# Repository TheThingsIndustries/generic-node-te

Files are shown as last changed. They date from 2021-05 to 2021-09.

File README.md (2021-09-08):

# Generic Node Tracker Edition (GNTE)

## About

The Generic Node Tracker Edition provides a reference HW design that features [Semtech LR1110](https://www.semtech.com/products/wireless-rf/lora-edge/lr1110) modem and an STM32L073 host MCU.

This repository contains all the necessary hardware and software files for the GNTE node.

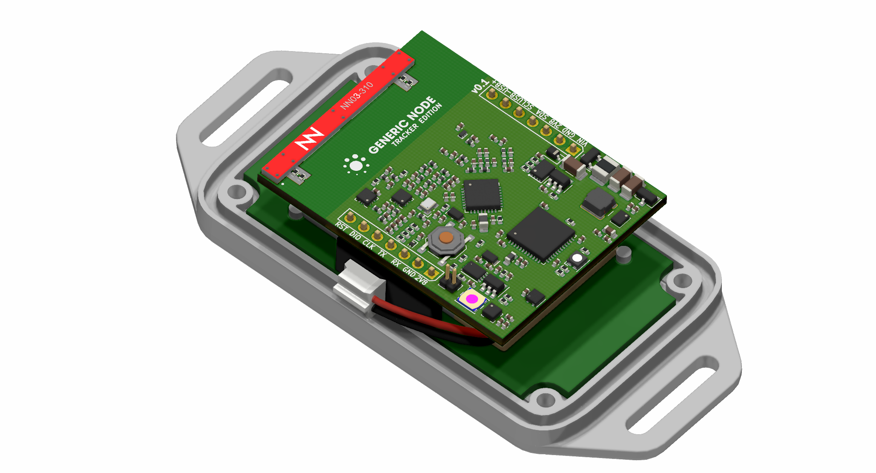
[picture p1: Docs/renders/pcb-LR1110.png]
Generic Node Tracker Edition PCB


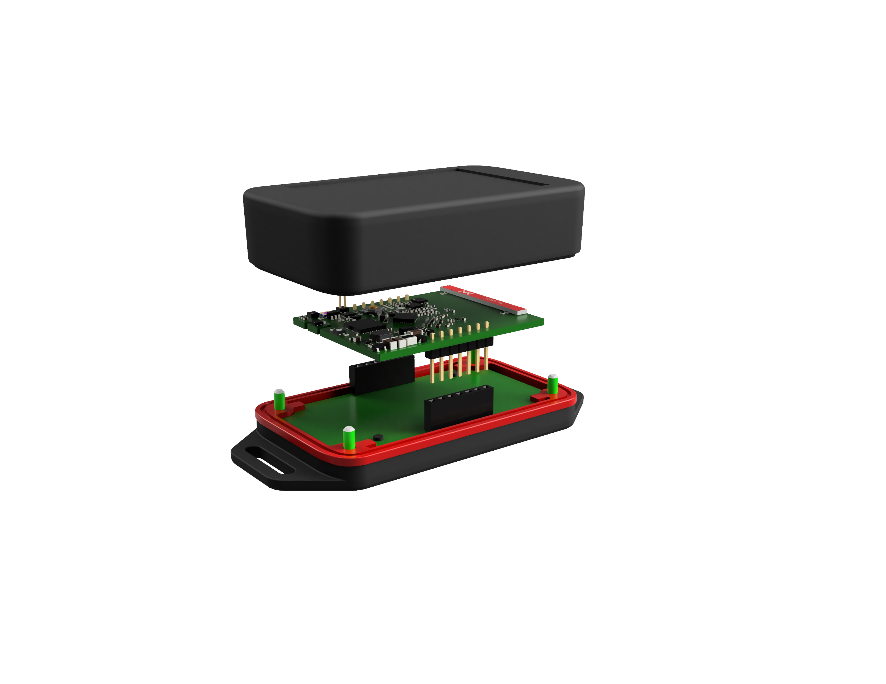
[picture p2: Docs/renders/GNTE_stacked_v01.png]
Generic Node Tracker Edition Stacked


## Documentation

The [Generic Node documentation website](https://www.genericnode.com/docs/) provides information about the node hardware and software features.

## Acknowledgment

The [Software](./Software) featured in this repository is a fork of Semtech [lr1110_modem_application_example](https://github.com/Lora-net/lr1110_modem_application_example) with minor changes that reflect the HW design.

## Legal

[Generic Node license terms and conditions](./LICENSE.md) apply.

[Contact The Things Industries](https://thethingsindustries.com/contact/) for licensing.

Copyright © 2021 The Things Industries B.V.

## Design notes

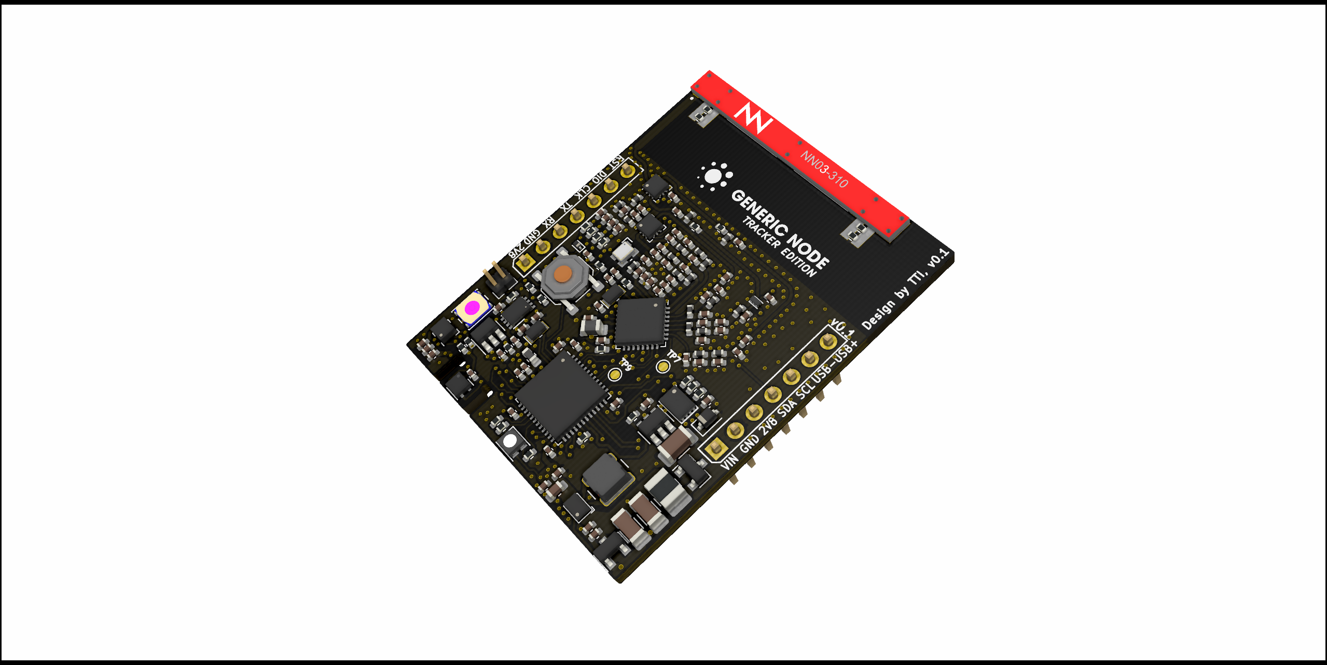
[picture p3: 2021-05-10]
Docs/renders/pcb-LR1110-02.png

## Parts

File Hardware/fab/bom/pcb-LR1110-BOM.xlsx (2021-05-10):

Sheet: pcb-LR1110
Source: | C:\Users\orkha\OneDrive\TTI_Files\Generic_Node_TE\Hardware\pcb\pcb-LR1110.sch
Date: | 2/17/2021 2:02:27 PM
Tool: | Eeschema (5.1.8)-1
Generator: | C:\Program Files\KiCad\bin\scripting\plugins/bom_csv_grouped_by_value.py
Component Count: | 150
Individual Components:
Collated Components:
Item | Qty | Reference(s) | Value | MPN | ALT_MPN | LibPart | Footprint
1 | 1 | AE1 | NN03-310 | NN03-310 |  | lr1110-lib:NN03-310 | lr1110-lib:NN03-310_S
2 | 7 | C1, C8, C11, C12, C43, C69, C70 | 1uF | CL05A105KQ5NNNC |  | Device:C | Capacitor_SMD:C_0402_1005Metric
3 | 14 | C2, C7, C10, C32, C33, C36, C37, C38, C40, C42, C67, C68, C71, C72 | 100nF | CC0402KRX7R7BB104 |  | Device:C | Capacitor_SMD:C_0402_1005Metric
4 | 3 | C3, C4, C5 | 100uF | JMK316ABJ107ML-T |  | Device:C | Capacitor_SMD:C_1206_3216Metric
5 | 1 | C6 | 470pF | CL05C471JO5NNNC |  | Device:C_Small | Capacitor_SMD:C_0402_1005Metric
6 | 1 | C9 | 22uF | CC0603MRX5R5BB226 | JMK107BBJ226MA | Device:C | Capacitor_SMD:C_0603_1608Metric
7 | 2 | C13, C34 | 100nF | CC0402KRX7R7BB104 |  | Device:C_Small | Capacitor_SMD:C_0402_1005Metric
8 | 2 | C14, C48 | 1.2pF | GRM1555C1H1R2BA01D |  | Device:C_Small | Capacitor_SMD:C_0402_1005Metric
9 | 7 | C15, C17, C47, C57, C58, C65, C66 | 1nF | GRM155R71C102KA01D |  | Device:C_Small | Capacitor_SMD:C_0402_1005Metric
10 | 5 | C16, C27, C28, C41, C46 | 47pF | GRM1555C1H470JA01D |  | Device:C_Small | Capacitor_SMD:C_0402_1005Metric
11 | 2 | C18, C30 | 6.8pF | GRM1555C1H6R8CA01D |  | Device:C_Small | Capacitor_SMD:C_0402_1005Metric
12 | 1 | C20 | 10pF | C0402C100K5RAC7867 |  | Device:C_Small | Capacitor_SMD:C_0402_1005Metric
13 | 1 | C21 | 1.8pF | GRM1555C1H1R8BA01D |  | Device:C_Small | Capacitor_SMD:C_0402_1005Metric
14 | 4 | C22, C23, C73, C74 | 5.6pF | CC0402BRNPO9BN5R6 |  | Device:C_Small | Capacitor_SMD:C_0402_1005Metric
15 | 1 | C24 | 2pF | GJM1555C1H2R0WB01 |  | Device:C_Small | Capacitor_SMD:C_0402_1005Metric
16 | 2 | C25, C52 | 1.1pF | GJM1555C1H1R1WB01 |  | Device:C_Small | Capacitor_SMD:C_0402_1005Metric
17 | 1 | C26 | 2.2nF | GRM155R71H222KA01D |  | Device:C_Small | Capacitor_SMD:C_0402_1005Metric
18 | 1 | C29 | 3pF | GRM1555C1H3R0BA01J |  | Device:C_Small | Capacitor_SMD:C_0402_1005Metric
19 | 1 | C35 | 10uF | JMK107ABJ106KA-T | C1608X5R0J106K080AB | Device:C | Capacitor_SMD:C_0402_1005Metric
20 | 3 | C39, C45, C50 | 1.5pF | GRM1555C1H1R5BA01D |  | Device:C_Small | Capacitor_SMD:C_0402_1005Metric
21 | 2 | C44, C54 | 47pF | GRM1555C1H470JA01D |  | Device:C | Capacitor_SMD:C_0402_1005Metric
22 | 2 | C49, C60 | DNM | ~ |  | Device:C_Small | Capacitor_SMD:C_0402_1005Metric
23 | 1 | C51 | 12pF | GRM1555C1H120JA01D |  | Device:C_Small | Capacitor_SMD:C_0402_1005Metric
24 | 2 | C53, C56 | 0.5pF | GRM1555C1HR50BA01D |  | Device:C_Small | Capacitor_SMD:C_0402_1005Metric
25 | 1 | C55 | 1pF | GRM1555C1H1R0BA01D |  | Device:C_Small | Capacitor_SMD:C_0402_1005Metric
26 | 1 | C59 | 0.3pF | GJM1555C1HR30WB01 |  | Device:C_Small | Capacitor_SMD:C_0402_1005Metric
27 | 1 | C61 | 33pF | GRM1555C1H330JA01D |  | Device:C_Small | Capacitor_SMD:C_0402_1005Metric
28 | 1 | C62 | 1.3pF | GRM1555C1H1R3BA01D |  | Device:C_Small | Capacitor_SMD:C_0402_1005Metric
29 | 1 | C63 | 1.6pF | GRM1555C1H1R6BA01D |  | Device:C_Small | Capacitor_SMD:C_0402_1005Metric
30 | 1 | C64 | 0.7pF | GRM1555C1HR70BA01D |  | Device:C_Small | Capacitor_SMD:C_0402_1005Metric
31 | 1 | D1 | PESD5V0S1BA | PESD5V0S1BA,115 |  | Device:D_TVS_ALT | Diode_SMD:D_SOD-323
32 | 1 | D2 | FM-B2020RGBA | FM-B2020RGBA-HG |  | pcb-LR1110-rescue:FM-B2020RGBA-node-lib-v1-pcb-LR1110-rescue | LED_SMD:LED_Cree-PLCC4_2x2mm_CW
33 | 1 | D4 | ESD9D5V | Diode_SMD:D_SOD-923 |  | Device:D_Zener | Diode_SMD:D_SOD-923
34 | 1 | F1 | PTC 13V 1A | SMD1210-050 |  | Device:Polyfuse | Fuse:Fuse_1210_3225Metric_Castellated
35 | 1 | FB1 | 600R @100MHz | BLM18AG601SN1D |  | Device:Ferrite_Bead_Small | Inductor_SMD:L_0603_1608Metric
36 | 1 | J2 | BOOT0 | DNM |  | Connector_Generic:Conn_01x02 | Connector_PinHeader_1.27mm:PinHeader_1x02_P1.27mm_Vertical
37 | 1 | J8 | DEBUG | DNM | C124418 | Connector_Generic:Conn_01x07 | Connector_PinSocket_2.54mm:PinSocket_1x07_P2.54mm_Vertical
38 | 1 | J9 | USB/I2C | DNM | C124418 | Connector_Generic:Conn_01x07 | Connector_PinSocket_2.54mm:PinSocket_1x07_P2.54mm_Vertical
39 | 1 | JP3 | NetTie | DNM |  | Device:Jumper_NC_Small | Jumper:SolderJumper-2_P1.3mm_Bridged2Bar_Pad1.0x1.5mm
40 | 1 | L1 | 2.2uH | HPC4012TF-2R2M |  | Device:L_Core_Ferrite | node-lib-v1:L_HPC4012TF-2R2M
41 | 1 | L2 | 10R @100MHz | BLM15HG102SN1D |  | Device:L_Small | Inductor_SMD:L_0402_1005Metric
42 | 1 | L3 | 3.3nH | LQW15AN3N3C80D |  | Device:L_Small | Inductor_SMD:L_0402_1005Metric
43 | 1 | L4 | 8.2nH | LQW15AN8N2J00D |  | Device:L_Small | Inductor_SMD:L_0402_1005Metric
44 | 3 | L5, L7, L12 | 47nH | LQW15AN47NJ00D |  | Device:L_Small | Inductor_SMD:L_0402_1005Metric
45 | 1 | L6 | 5.9nH | LQW15AN5N9G80 |  | Device:L_Small | Inductor_SMD:L_0402_1005Metric
46 | 3 | L8, L13, L14 | 9.5nH | LQW18AN9N5G80 |  | Device:L_Small | Inductor_SMD:L_0402_1005Metric
47 | 1 | L9 | 2.7nH | LQW15AN2N7C00D |  | Device:L_Small | Inductor_SMD:L_0402_1005Metric
48 | 1 | L10 | 6.8nH | LQW15AN6N8J00D |  | Device:L_Small | Inductor_SMD:L_0402_1005Metric
49 | 1 | L11 | 22nH | LQW15AN22NH00D |  | Device:L_Small | Inductor_SMD:L_0402_1005Metric
50 | 1 | L15 | DNM | DNM |  | Device:L_Small | Inductor_SMD:L_0402_1005Metric
51 | 1 | L16 | 33nH | LQW15AN33NJ00D |  | Device:L_Small | Inductor_SMD:L_0402_1005Metric
52 | 1 | L17 | 7.9nH | LQW15AN7N9G80 |  | Device:L_Small | Inductor_SMD:L_0402_1005Metric
53 | 2 | L18, L19 | 3.6nH | LQW15AN3N6C10D |  | Device:L_Small | Inductor_SMD:L_0402_1005Metric
54 | 1 | L20 | 5.6nH | LQW15AN5N6G80 |  | Device:L_Small | Inductor_SMD:L_0402_1005Metric
55 | 1 | L21 | 15uH | MLZ2012M150W |  | Device:L | Inductor_SMD:L_0805_2012Metric
56 | 1 | N1 | BoLink-16174435 | DNM | BL 704020 WL2-9005 | Mechanical:Housing | lr1110-lib:BoLink_704025
57 | 1 | Q1 | CEN2321A | CEN2321A |  | Device:Q_PMOS_GSD | Package_TO_SOT_SMD:SOT-23
58 | 1 | R1 | 220R | RC0402FR-07220RL |  | Device:R_US | Resistor_SMD:R_0402_1005Metric
59 | 3 | R2, R3, R4 | 100K | RC0402FR-07100KL |  | Device:R | Resistor_SMD:R_0402_1005Metric
60 | 11 | R5, R17, R18, R19, R20, R21, R24, R25, R26, R27, R28 | 0R |  |  | Device:R_US | Resistor_SMD:R_0402_1005Metric
61 | 1 | R6 | 1K | RC0402FR-071KL |  | Device:R | Resistor_SMD:R_0402_1005Metric
62 | 2 | R7, R8 | 330R | AC0402FR-07330RL |  | Device:R | Resistor_SMD:R_0402_1005Metric
63 | 2 | R10, R11 | DNM | DNM |  | Device:R | Resistor_SMD:R_0402_1005Metric
64 | 1 | R12 | 10K | AC0402JR-0710KL |  | Device:R | Resistor_SMD:R_0402_1005Metric
65 | 1 | R13 | 100R | RC0402FR-07100RL |  | Device:R | Resistor_SMD:R_0402_1005Metric
66 | 2 | R15, R16 | 4K7 | AC0402FR-074K7L |  | Device:R | Resistor_SMD:R_0402_1005Metric
67 | 2 | R22, R23 | DNM |  |  | Device:R_US | Resistor_SMD:R_0402_1005Metric
68 | 1 | R29 | 10K |  |  | Device:R_US | Resistor_SMD:R_0402_1005Metric
69 | 1 | SW1 | USR_BTN | KSC721GLFS |  | Switch:SW_Push | node-lib-v1:PushButton_UK-B0234-SP25Y
70 | 1 | SW2 | SW_Push |  |  | Switch:SW_Push | node-lib-v1:SW_SPST_SKSHABE010
71 | 1 | U1 | RP605Z283B | RP605Z283B-E2-F |  | pcb-LR1110-rescue:RP605Zx-node-lib-v1-pcb-LR1110-rescue | node-lib-v1:WLCSP-20-P3_1.994x1.609mm_Layout5x4_P0.4mm
72 | 1 | U2 | TPS3839G25 | TPS3839G25DBZ |  | Power_Supervisor:TPS3839DBZ | Package_TO_SOT_SMD:SOT-23
73 | 2 | U3, U4 | TPS22917DBV | TPS22917DBVR |  | Power_Management:TPS22917DBV | Package_TO_SOT_SMD:SOT-23-6
74 | 2 | U5, U6 | SKY13588-460LF | SKY13588-460LF |  | lr1110-lib:SKY13588-460LF | lr1110-lib:sQFN-12-1EP_2x2mm_P0.5mm_EP0.76x0.76mm
75 | 1 | U7 | BGA524N6 | BGA524N6 |  | lr1110-lib:BGA524N6 | lr1110-lib:TSNP-6-2-8
76 | 1 | U8 | STM32L073CZU6 | STM32L073CZU6 |  | lr1110-lib:STM32L073CZUx | Package_DFN_QFN:QFN-48-1EP_7x7mm_P0.5mm_EP5.45x5.45mm
77 | 1 | U9 | LR1110IMLTRT | LR1110IMLTRT |  | lr1110-lib:LR1110IMLTRT | Package_DFN_QFN:QFN-32-1EP_5x5mm_P0.5mm_EP3.7x3.7mm
78 | 1 | U10 | MX25R1635 | MX25R1635FZUIL0 |  | pcb-LR1110-rescue:MX25R1635-node-lib-v1-pcb-LR1110-rescue | node-lib-v1:FLASH_UFDFN-8-MX25R1635F
79 | 1 | U11 | ATECC608A-TNGLORA | ATECC608A-TNGLORAU-B |  | Security:ATECC608A-MAHDA | Package_DFN_QFN:DFN-8-1EP_3x2mm_P0.5mm_EP1.3x1.5mm
80 | 1 | U12 | LIS2DH12 | LIS2DH12TR |  | pcb-LR1110-rescue:LIS2DH12-node-lib-v1-pcb-LR1110-rescue | Package_LGA:LGA-12_2x2mm_P0.5mm
81 | 1 | U13 | SHTC3 | SHTC3 |  | Sensor_Humidity:SHTC3 | node-lib-v1:Sensirion_DFN-4-1EP_2x2mm_P1mm_EP0.7x1.6mm
82 | 1 | X1 | 32MHz | TYETBCSANF-32.000000 |  | pcb-LR1110-rescue:TCXO-xxxMHz-node-lib-v1-pcb-LR1110-rescue | Crystal:Crystal_SMD_Abracon_ABM10-4Pin_2.5x2.0mm
83 | 2 | Y1, Y2 | 32.768KHz | X1A000061002100 |  | Device:Crystal | node-lib-v1:Crystal_SMD_NX2012SA_32.768KHz

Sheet: Sheet2
Item | Qty | Reference(s) | Value | MPN | Footprint
1 | 1 | AE1 | NN03-310 | NN03-310 | lr1110-lib:NN03-310_S
2 | 7 | C1, C8, C11, C12, C43, C69, C70 | 1uF | CL05A105KQ5NNNC | Capacitor_SMD:C_0402_1005Metric
3 | 14 | C2, C7, C10, C32, C33, C36, C37, C38, C40, C42, C67, C68, C71, C72 | 100nF | CC0402KRX7R7BB104 | Capacitor_SMD:C_0402_1005Metric
4 | 3 | C3, C4, C5 | 100uF | JMK316ABJ107ML-T | Capacitor_SMD:C_1206_3216Metric
5 | 1 | C6 | 470pF | CL05C471JO5NNNC | Capacitor_SMD:C_0402_1005Metric
6 | 1 | C9 | 22uF | CC0603MRX5R5BB226 | Capacitor_SMD:C_0603_1608Metric
7 | 2 | C13, C34 | 100nF | CC0402KRX7R7BB104 | Capacitor_SMD:C_0402_1005Metric
8 | 2 | C14, C48 | 1.2pF | GRM1555C1H1R2BA01D | Capacitor_SMD:C_0402_1005Metric
9 | 7 | C15, C17, C47, C57, C58, C65, C66 | 1nF | GRM155R71C102KA01D | Capacitor_SMD:C_0402_1005Metric
10 | 5 | C16, C27, C28, C41, C46 | 47pF | GRM1555C1H470JA01D | Capacitor_SMD:C_0402_1005Metric
11 | 2 | C18, C30 | 6.8pF | GRM1555C1H6R8CA01D | Capacitor_SMD:C_0402_1005Metric
12 | 1 | C20 | 10pF | C0402C100K5RAC7867 | Capacitor_SMD:C_0402_1005Metric
13 | 1 | C21 | 1.8pF | GRM1555C1H1R8BA01D | Capacitor_SMD:C_0402_1005Metric
14 | 4 | C22, C23, C73, C74 | 5.6pF | CC0402BRNPO9BN5R6 | Capacitor_SMD:C_0402_1005Metric
15 | 1 | C24 | 2pF | GJM1555C1H2R0WB01 | Capacitor_SMD:C_0402_1005Metric
16 | 2 | C25, C52 | 1.1pF | GJM1555C1H1R1WB01 | Capacitor_SMD:C_0402_1005Metric
17 | 1 | C26 | 2.2nF | GRM155R71H222KA01D | Capacitor_SMD:C_0402_1005Metric
18 | 1 | C29 | 3pF | GRM1555C1H3R0BA01J | Capacitor_SMD:C_0402_1005Metric
19 | 1 | C35 | 10uF | JMK107ABJ106KA-T | Capacitor_SMD:C_0402_1005Metric
20 | 3 | C39, C45, C50 | 1.5pF | GRM1555C1H1R5BA01D | Capacitor_SMD:C_0402_1005Metric
21 | 2 | C44, C54 | 47pF | GRM1555C1H470JA01D | Capacitor_SMD:C_0402_1005Metric
22 | 2 | C49, C60 | DNM | ~ | Capacitor_SMD:C_0402_1005Metric
23 | 1 | C51 | 12pF | GRM1555C1H120JA01D | Capacitor_SMD:C_0402_1005Metric
24 | 2 | C53, C56 | 0.5pF | GRM1555C1HR50BA01D | Capacitor_SMD:C_0402_1005Metric
25 | 1 | C55 | 1pF | GRM1555C1H1R0BA01D | Capacitor_SMD:C_0402_1005Metric
26 | 1 | C59 | 0.3pF | GJM1555C1HR30WB01 | Capacitor_SMD:C_0402_1005Metric
27 | 1 | C61 | 33pF | GRM1555C1H330JA01D | Capacitor_SMD:C_0402_1005Metric
28 | 1 | C62 | 1.3pF | GRM1555C1H1R3BA01D | Capacitor_SMD:C_0402_1005Metric
29 | 1 | C63 | 1.6pF | GRM1555C1H1R6BA01D | Capacitor_SMD:C_0402_1005Metric
30 | 1 | C64 | 0.7pF | GRM1555C1HR70BA01D | Capacitor_SMD:C_0402_1005Metric
31 | 1 | D1 | PESD5V0S1BA | PESD5V0S1BA,115 | Diode_SMD:D_SOD-323
32 | 1 | D2 | FM-B2020RGBA | FM-B2020RGBA-HG | LED_SMD:LED_Cree-PLCC4_2x2mm_CW
33 | 1 | D4 | ESD9D5V | Diode_SMD:D_SOD-923 | Diode_SMD:D_SOD-923
34 | 1 | F1 | PTC 13V 1A | SMD1210-050 | Fuse:Fuse_1210_3225Metric_Castellated
35 | 1 | FB1 | 600R @100MHz | BLM18AG601SN1D | Inductor_SMD:L_0603_1608Metric
36 | 1 | J2 | BOOT0 | DNM | Connector_PinHeader_1.27mm:PinHeader_1x02_P1.27mm_Vertical
37 | 1 | J8 | DEBUG | DNM | Connector_PinSocket_2.54mm:PinSocket_1x07_P2.54mm_Vertical
38 | 1 | J9 | USB/I2C | DNM | Connector_PinSocket_2.54mm:PinSocket_1x07_P2.54mm_Vertical
39 | 1 | JP3 | NetTie | DNM | Jumper:SolderJumper-2_P1.3mm_Bridged2Bar_Pad1.0x1.5mm
40 | 1 | L1 | 2.2uH | HPC4012TF-2R2M | node-lib-v1:L_HPC4012TF-2R2M
41 | 1 | L2 | 10R @100MHz | BLM15HG102SN1D | Inductor_SMD:L_0402_1005Metric
42 | 1 | L3 | 3.3nH | LQW15AN3N3C80D | Inductor_SMD:L_0402_1005Metric
43 | 1 | L4 | 8.2nH | LQW15AN8N2J00D | Inductor_SMD:L_0402_1005Metric
44 | 3 | L5, L7, L12 | 47nH | LQW15AN47NJ00D | Inductor_SMD:L_0402_1005Metric
45 | 1 | L6 | 5.9nH | LQW15AN5N9G80 | Inductor_SMD:L_0402_1005Metric
46 | 3 | L8, L13, L14 | 9.5nH | LQW18AN9N5G80 | Inductor_SMD:L_0402_1005Metric
47 | 1 | L9 | 2.7nH | LQW15AN2N7C00D | Inductor_SMD:L_0402_1005Metric
48 | 1 | L10 | 6.8nH | LQW15AN6N8J00D | Inductor_SMD:L_0402_1005Metric
49 | 1 | L11 | 22nH | LQW15AN22NH00D | Inductor_SMD:L_0402_1005Metric
50 | 1 | L15 | DNM | DNM | Inductor_SMD:L_0402_1005Metric
51 | 1 | L16 | 33nH | LQW15AN33NJ00D | Inductor_SMD:L_0402_1005Metric
52 | 1 | L17 | 7.9nH | LQW15AN7N9G80 | Inductor_SMD:L_0402_1005Metric
53 | 2 | L18, L19 | 3.6nH | LQW15AN3N6C10D | Inductor_SMD:L_0402_1005Metric
54 | 1 | L20 | 5.6nH | LQW15AN5N6G80 | Inductor_SMD:L_0402_1005Metric
55 | 1 | L21 | 15uH | MLZ2012M150W | Inductor_SMD:L_0805_2012Metric
56 | 1 | N1 | BoLink-16174435 | DNM | lr1110-lib:BoLink_704025
57 | 1 | Q1 | CEN2321A | CEN2321A | Package_TO_SOT_SMD:SOT-23
58 | 1 | R1 | 220R | RC0402FR-07220RL | Resistor_SMD:R_0402_1005Metric
59 | 3 | R2, R3, R4 | 100K | RC0402FR-07100KL | Resistor_SMD:R_0402_1005Metric
60 | 11 | R5, R17, R18, R19, R20, R21, R24, R25, R26, R27, R28 | 0R |  | Resistor_SMD:R_0402_1005Metric
61 | 1 | R6 | 1K | RC0402FR-071KL | Resistor_SMD:R_0402_1005Metric
62 | 2 | R7, R8 | 330R | AC0402FR-07330RL | Resistor_SMD:R_0402_1005Metric
63 | 2 | R10, R11 | DNM | DNM | Resistor_SMD:R_0402_1005Metric
64 | 1 | R12 | 10K | AC0402JR-0710KL | Resistor_SMD:R_0402_1005Metric
65 | 1 | R13 | 100R | RC0402FR-07100RL | Resistor_SMD:R_0402_1005Metric
66 | 2 | R15, R16 | 4K7 | AC0402FR-074K7L | Resistor_SMD:R_0402_1005Metric
67 | 2 | R22, R23 | DNM |  | Resistor_SMD:R_0402_1005Metric
68 | 1 | R29 | 10K |  | Resistor_SMD:R_0402_1005Metric
69 | 1 | SW1 | USR_BTN | KSC721GLFS | node-lib-v1:PushButton_UK-B0234-SP25Y
70 | 1 | SW2 | SW_Push |  | node-lib-v1:SW_SPST_SKSHABE010
71 | 1 | U1 | RP605Z283B | RP605Z283B-E2-F | node-lib-v1:WLCSP-20-P3_1.994x1.609mm_Layout5x4_P0.4mm
72 | 1 | U2 | TPS3839G25 | TPS3839G25DBZ | Package_TO_SOT_SMD:SOT-23
73 | 2 | U3, U4 | TPS22917DBV | TPS22917DBVR | Package_TO_SOT_SMD:SOT-23-6
74 | 2 | U5, U6 | SKY13588-460LF | SKY13588-460LF | lr1110-lib:sQFN-12-1EP_2x2mm_P0.5mm_EP0.76x0.76mm
75 | 1 | U7 | BGA524N6 | BGA524N6 | lr1110-lib:TSNP-6-2-8
76 | 1 | U8 | STM32L073CZU6 | STM32L073CZU6 | Package_DFN_QFN:QFN-48-1EP_7x7mm_P0.5mm_EP5.45x5.45mm
77 | 1 | U9 | LR1110IMLTRT | LR1110IMLTRT | Package_DFN_QFN:QFN-32-1EP_5x5mm_P0.5mm_EP3.7x3.7mm
78 | 1 | U10 | MX25R1635 | MX25R1635FZUIL0 | node-lib-v1:FLASH_UFDFN-8-MX25R1635F
79 | 1 | U11 | ATECC608A-TNGLORA | ATECC608A-TNGLORAU-B | Package_DFN_QFN:DFN-8-1EP_3x2mm_P0.5mm_EP1.3x1.5mm
80 | 1 | U12 | LIS2DH12 | LIS2DH12TR | Package_LGA:LGA-12_2x2mm_P0.5mm
81 | 1 | U13 | SHTC3 | SHTC3 | node-lib-v1:Sensirion_DFN-4-1EP_2x2mm_P1mm_EP0.7x1.6mm
82 | 1 | X1 | 32MHz | TYETBCSANF-32.000000 | Crystal:Crystal_SMD_Abracon_ABM10-4Pin_2.5x2.0mm
83 | 2 | Y1, Y2 | 32.768KHz | X1A000061002100 | node-lib-v1:Crystal_SMD_NX2012SA_32.768KHz

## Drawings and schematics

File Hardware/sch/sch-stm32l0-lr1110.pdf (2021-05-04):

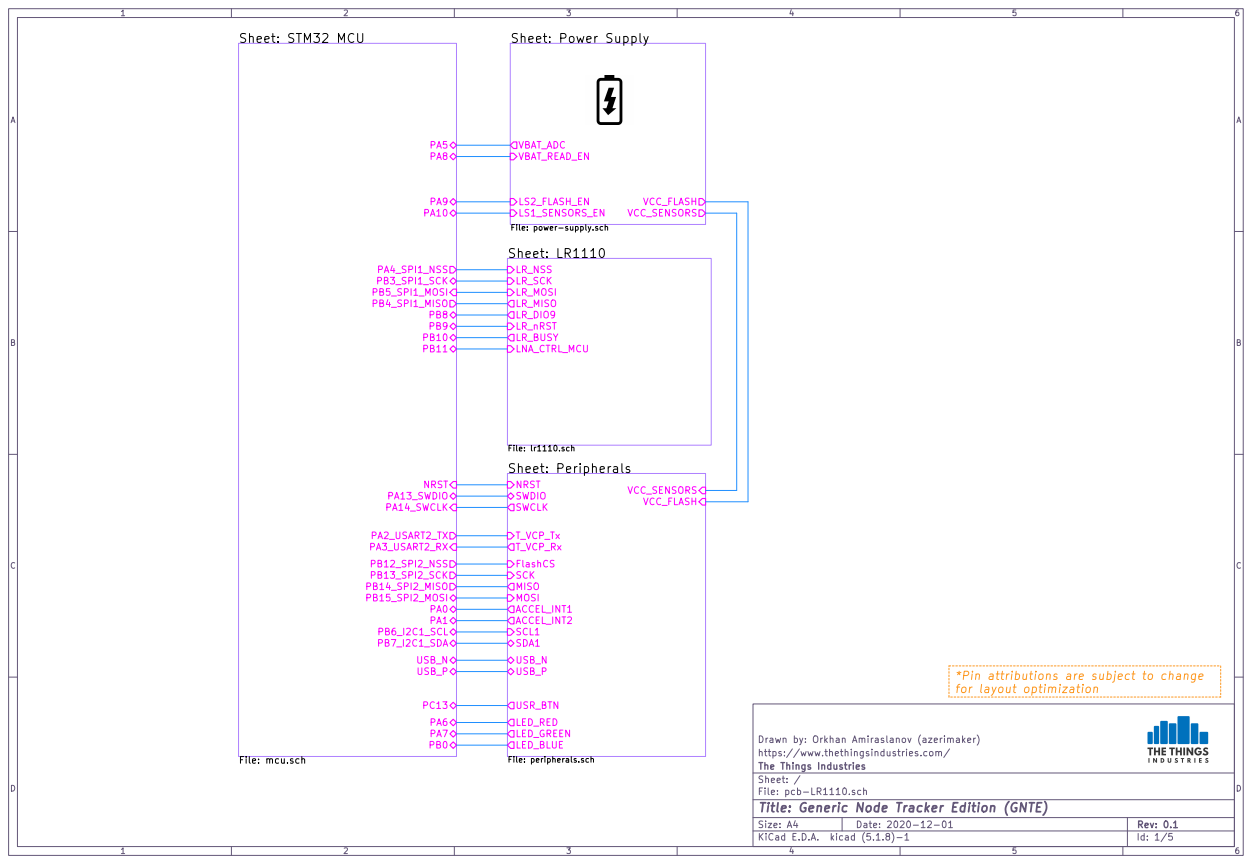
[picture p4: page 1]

*Pin attributions are subject to change
for layout optimization

Drawn by: Orkhan Amiraslanov (azerimaker)
https://www.thethingsindustries.com/
File: pcb-LR1110.sch Sheet: / The Things Industries

Id: 1/5 Title: Generic Node Tracker Edition (GNTE)

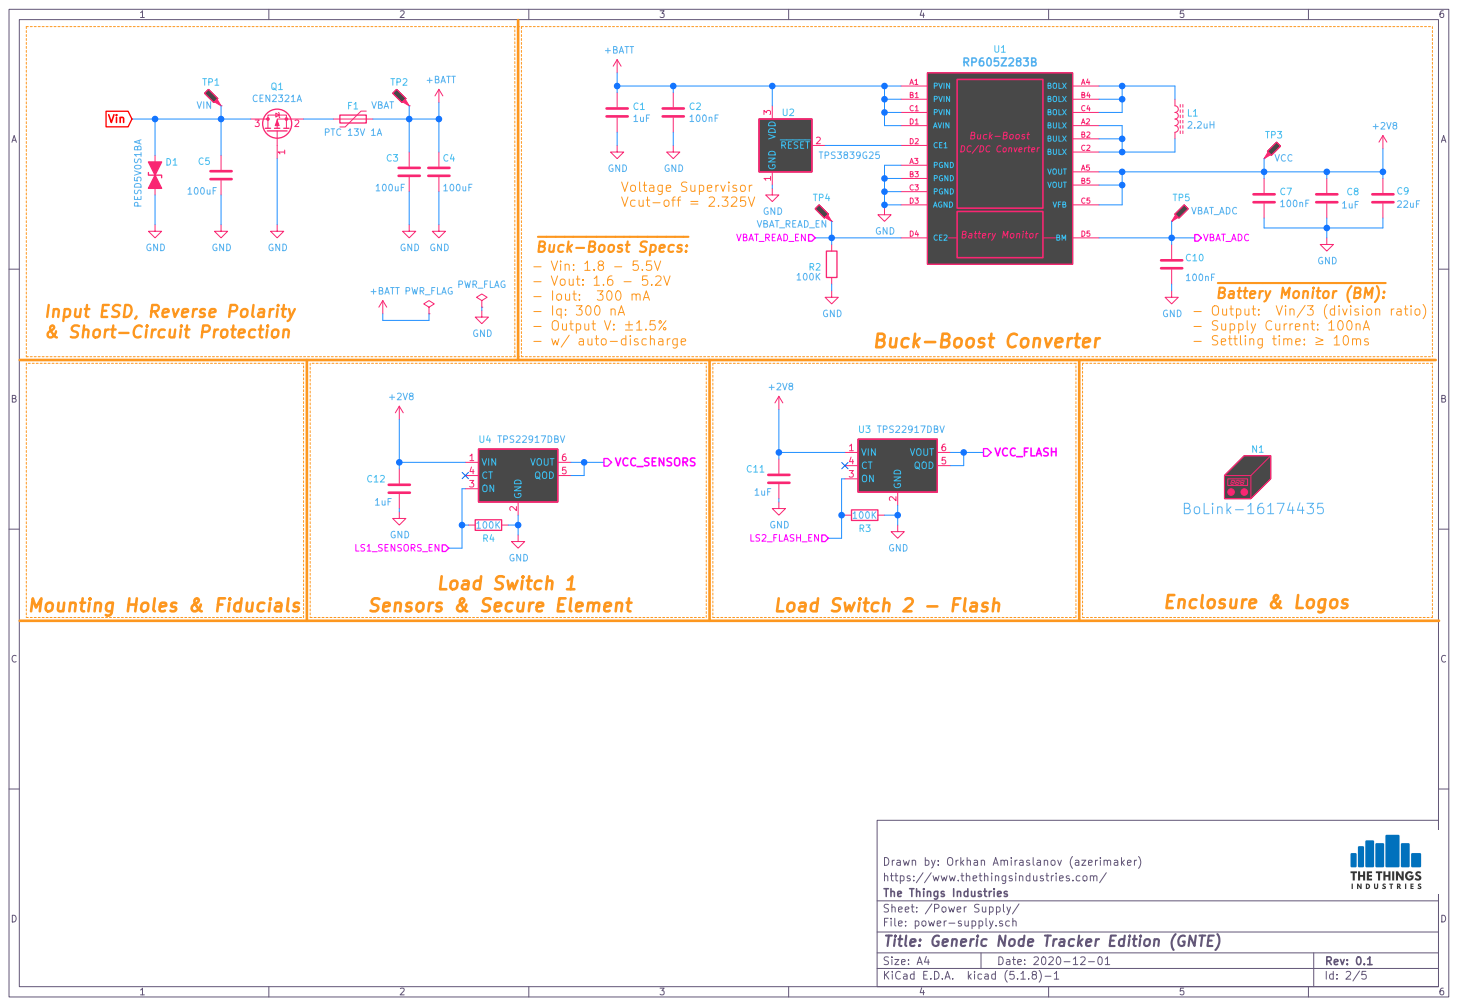
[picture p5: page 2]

Battery Monitor (BM):
- Output: Vin/3 (division ratio)
- Supply Current: 100nA
- Settling time: 10ms

Input ESD, Reverse Polarity
& Short-Circuit Protection

2 ON 3 CT 4 QOD 5 VOUT 6 U3 TPS22917DBV GND GND

2 ON 3 CT 4 QOD 5 VOUT 6 U4 TPS22917DBV

Drawn by: Orkhan Amiraslanov (azerimaker)
https://www.thethingsindustries.com/
The Things Industries
Sheet: /Power Supply/
File: power-supply.sch
Id: 2/5 Title: Generic Node Tracker Edition (GNTE)

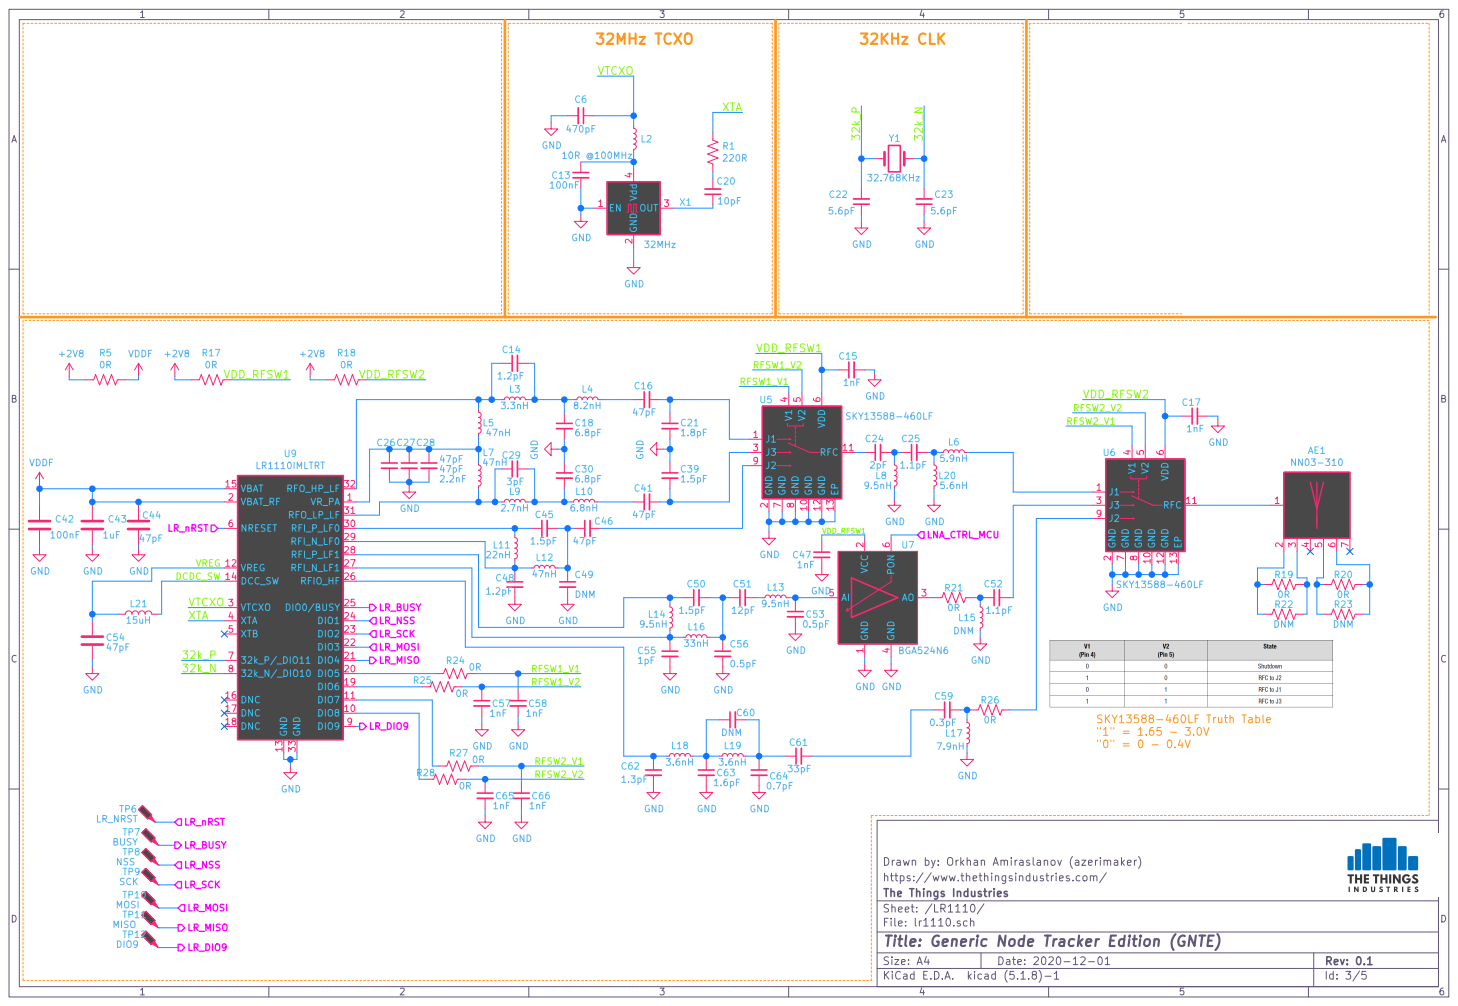
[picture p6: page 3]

2 OUT 3 Vdd
5.6pF GND GND GND GND

7 AE1 NN03-310 VR_PA 1 DIO8 10 DIO7 11 VREG 12 GND 13 DCC_SW 14 VBAT 15 DNC 16 DNC 17 DNC 18 DIO6 19 VBAT_RF 2 DIO5 20 DIO4 21 DIO3 22 DIO2 23 DIO1 24 DIO0/BUSY 25 RFIO_HF 26 RFI_N_LF1 27 RFI_P_LF1 28 RFI_N_LF0 29 VTCXO 3 RFI_P_LF0 30 RFO_LP_LF 31 RFO_HP_LF 32 GND 33 XTA 4 XTB 5 NRESET 6

https://www.thethingsindustries.com/
Id: 3/5 Title: Generic Node Tracker Edition (GNTE) File: lr1110.sch Sheet: /LR1110/ The Things Industries

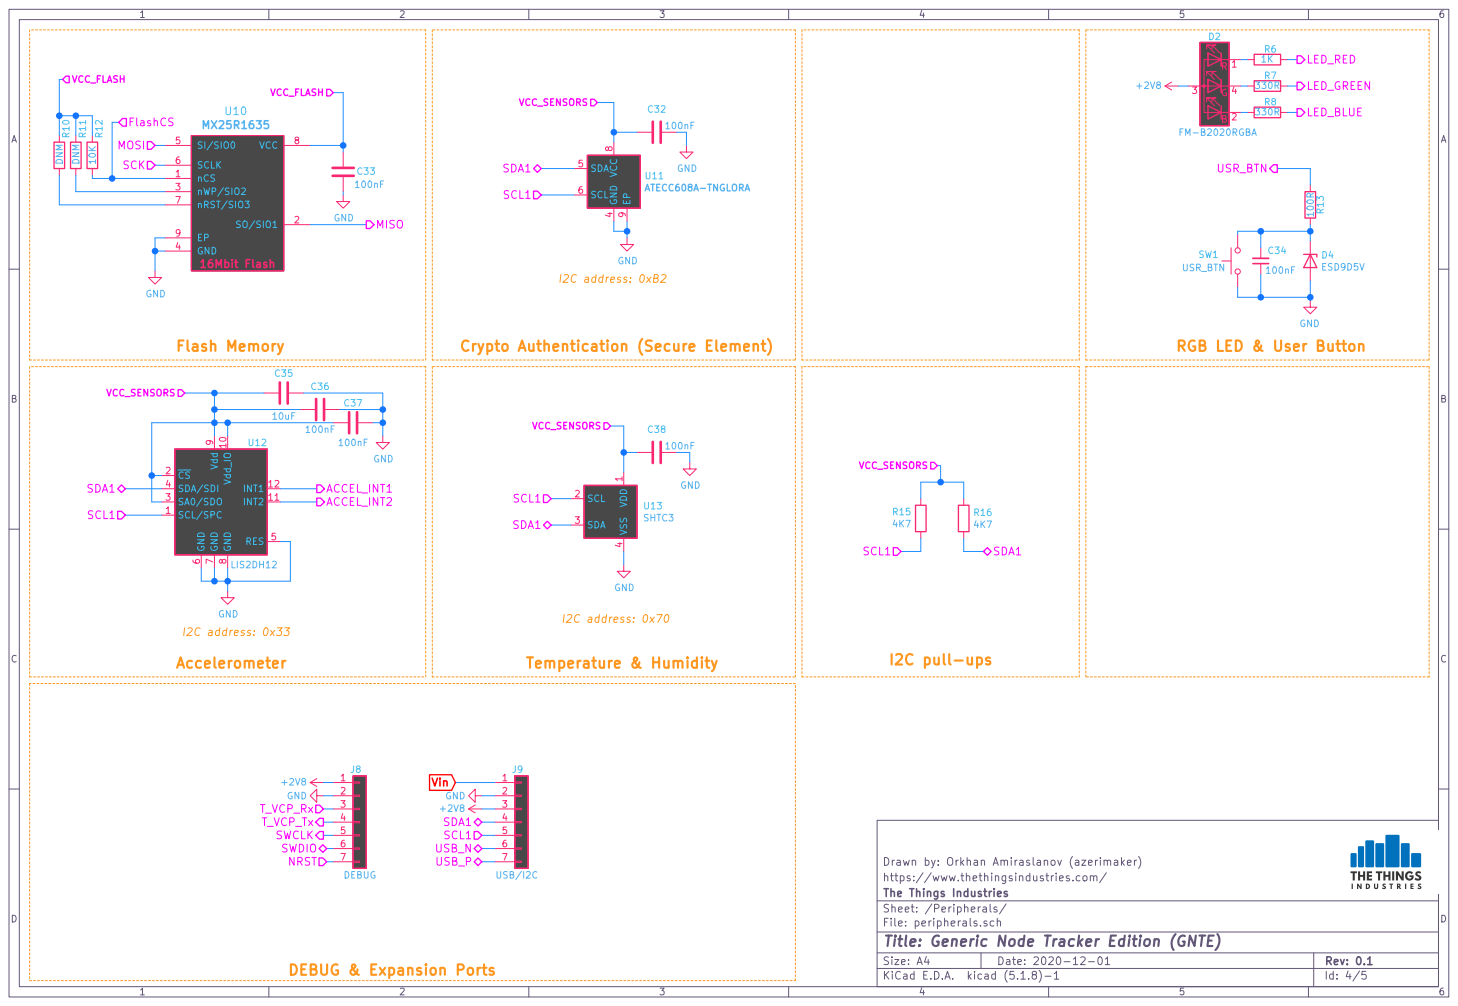
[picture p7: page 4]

VCC_FLASH
Drawn by: Orkhan Amiraslanov (azerimaker) R11 DNM

I2C address: 0x70 Crypto Authentication (Secure Element)

https://www.thethingsindustries.com/
The Things Industries
Sheet: /Peripherals/
File: peripherals.sch
Id: 4/5 Title: Generic Node Tracker Edition (GNTE)

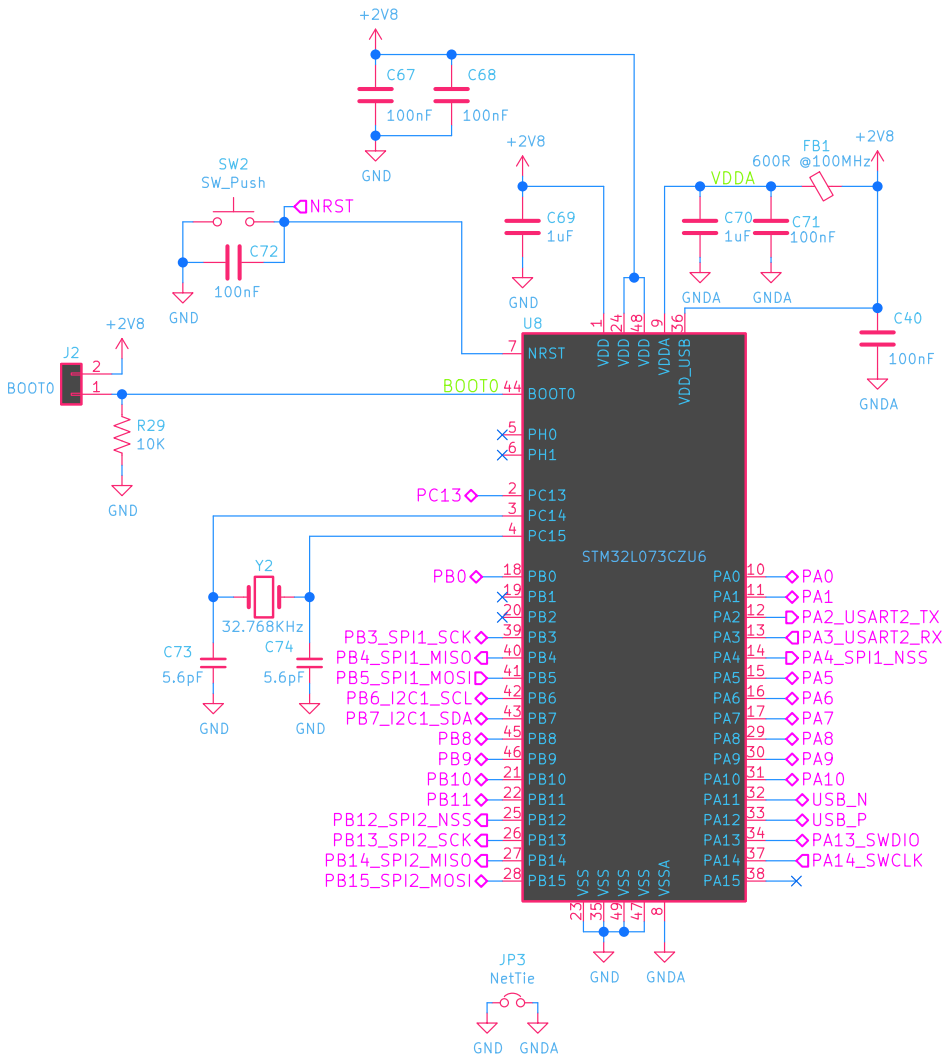
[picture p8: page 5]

1 PA0 10 PA1 11 PA2 12 PA3 13 PA4 14 PA5 15 PA6 16 PA7 17 PB0 18 PB1 19 PC13 2 PB2 20 PB10 21 PB11 22 VSS 23 VDD 24 PB12 25 PB13 26 PB14 27 PB15 28 PA8 29 PC14 3 PA9 30 PA10 31 PA11 32 PA12 33 PA13 34 VSS 35 VDD_USB 36 PA14 37 PA15 38 PB3 39 PC15 4 PB4 40 PB5 41 PB6 42 PB7 43 BOOT0 44 PB8 45 PB9 46 VSS 47 VDD 48 VSS 49 PH0 5 PH1 6 NRST 7 VSSA

Drawn by: Orkhan Amiraslanov (azerimaker)
https://www.thethingsindustries.com/
Id: 5/5 Title: Generic Node Tracker Edition (GNTE) File: mcu.sch Sheet: /STM32 MCU/ The Things Industries

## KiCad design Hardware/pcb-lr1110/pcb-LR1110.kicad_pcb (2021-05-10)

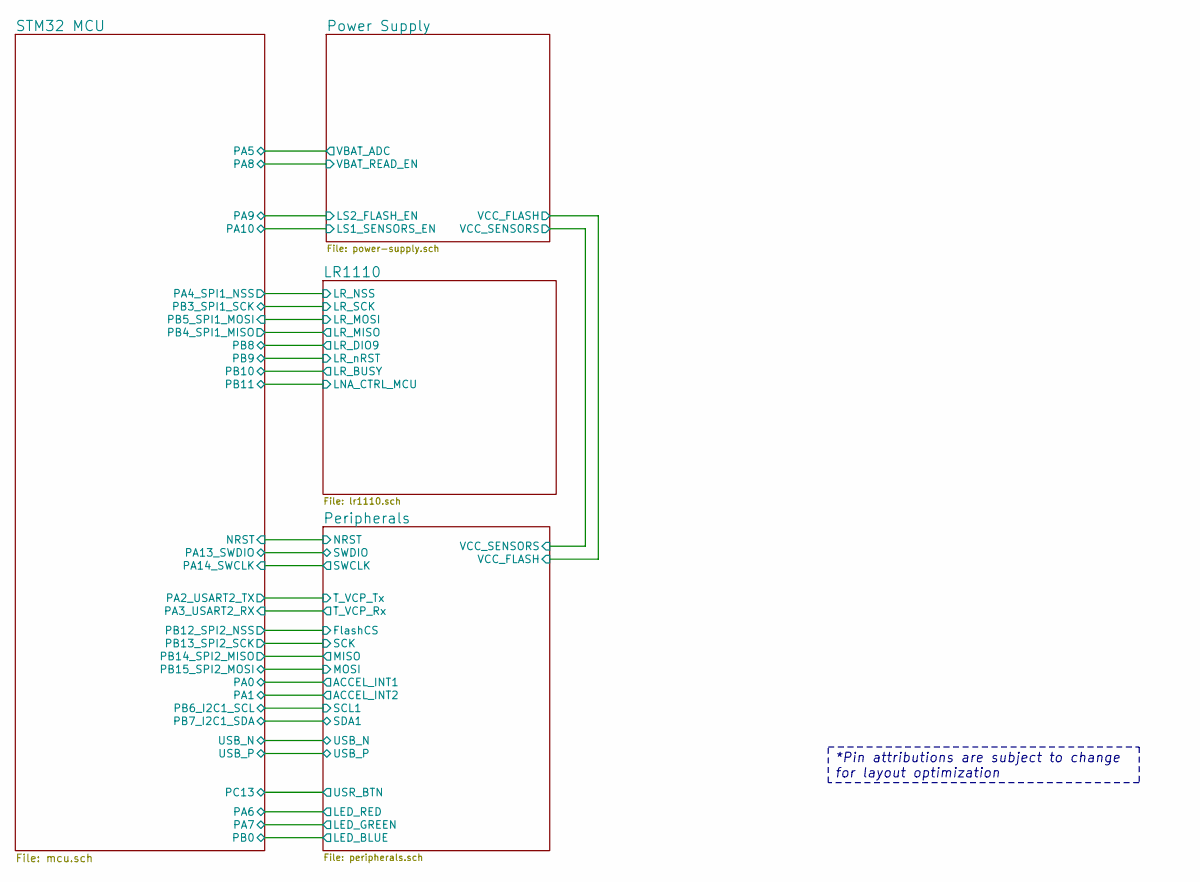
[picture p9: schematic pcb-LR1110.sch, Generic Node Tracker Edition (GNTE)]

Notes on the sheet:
*Pin attributions are subject to change for layout optimization

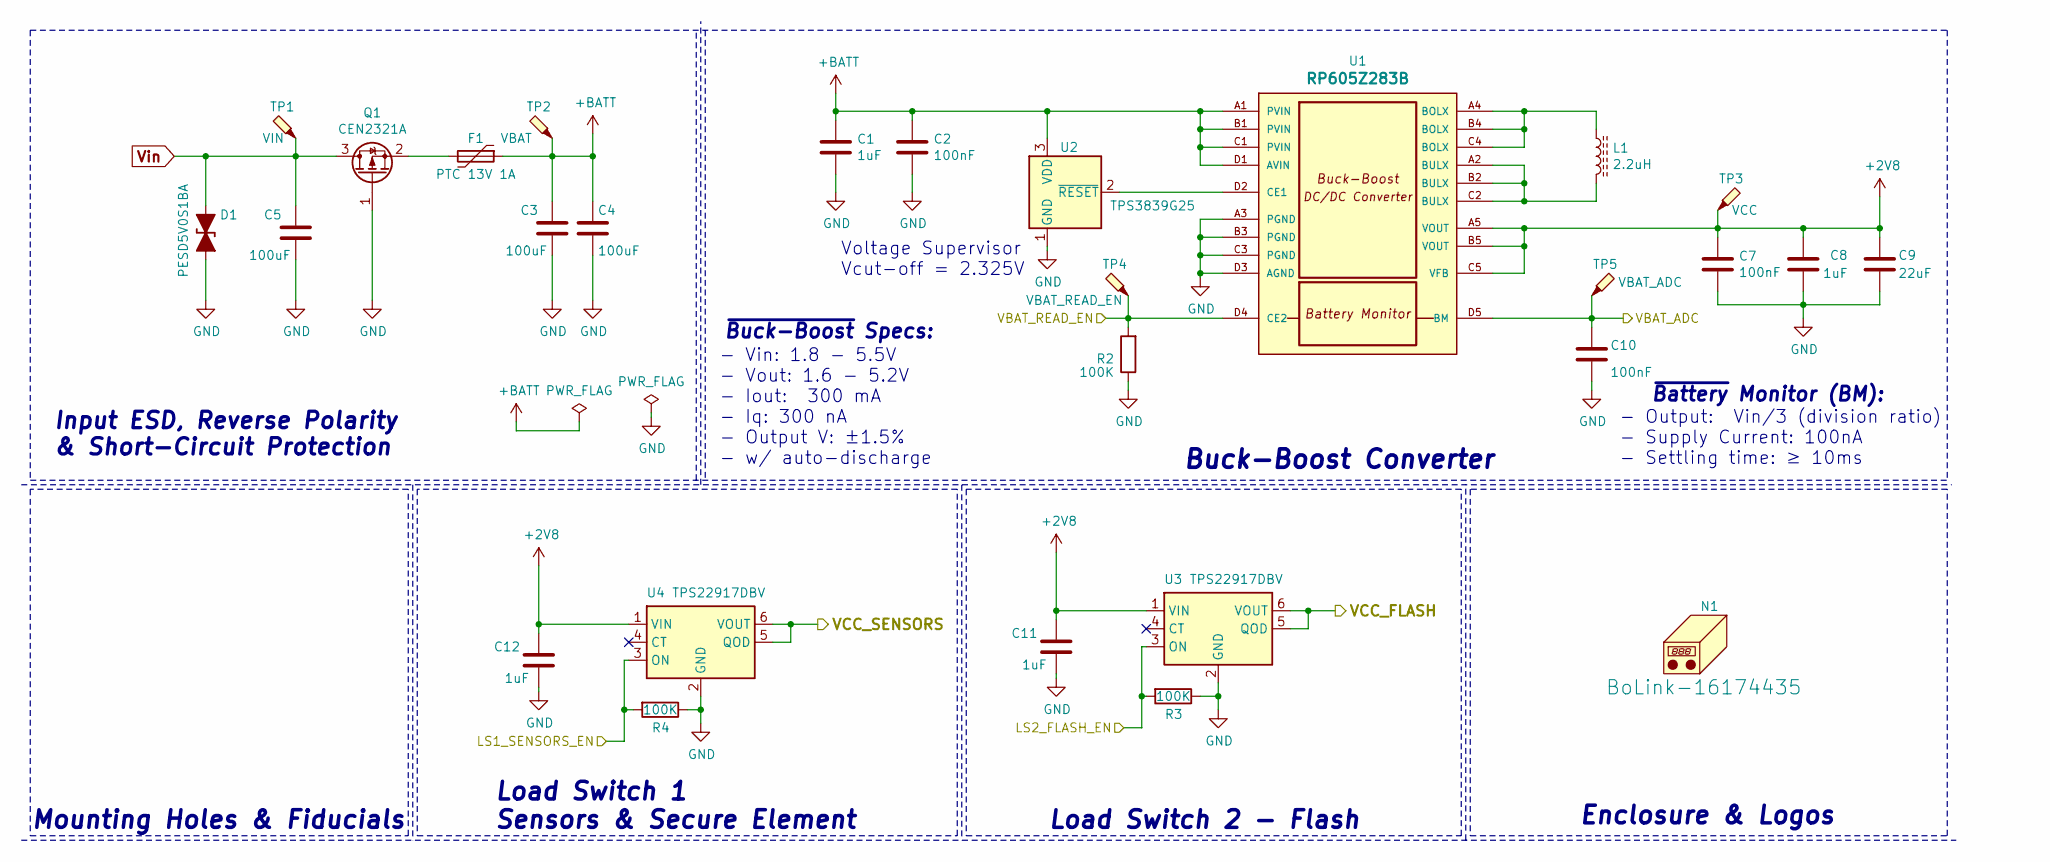
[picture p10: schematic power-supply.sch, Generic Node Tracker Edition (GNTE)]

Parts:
C1, C8, C11, C12: 1uF; C_0402_1005Metric; MPN CL05A105KQ5NNNC
C2, C7, C10: 100nF; C_0402_1005Metric; MPN CC0402KRX7R7BB104
C3, C4, C5: 100uF; C_1206_3216Metric; MPN JMK316ABJ107ML-T
C9: 22uF; C_0603_1608Metric; MPN CC0603MRX5R5BB226
D1: PESD5V0S1BA; D_SOD-323; MPN PESD5V0S1BA,115
F1: PTC 13V 1A; Fuse_1210_3225Metric_Castellated; MPN SMD1210-050
L1: 2.2uH; L_HPC4012TF-2R2M; MPN HPC4012TF-2R2M
N1: BoLink-16174435; BoLink_704025; MPN DNM
Q1: CEN2321A; SOT-23; MPN CEN2321A
R2, R3, R4: 100K; R_0402_1005Metric; MPN RC0402FR-07100KL
TP1: VIN; TestPoint_Pad_D1.5mm; MPN DNM
TP2: VBAT; TestPoint_Pad_D1.5mm; MPN DNM
TP3: VCC; TestPoint_Pad_D1.5mm; MPN DNM
TP4: VBAT_READ_EN; TestPoint_Pad_D1.5mm; MPN DNM
TP5: VBAT_ADC; TestPoint_Pad_D1.5mm; MPN DNM
U1: RP605Z283B; WLCSP-20-P3_1.994x1.609mm_Layout5x4_P0.4mm; MPN RP605Z283B-E2-F
U2: TPS3839G25; SOT-23; MPN TPS3839G25DBZ
U3, U4: TPS22917DBV; SOT-23-6; MPN TPS22917DBVR

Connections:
+2V8: C7.2, C8.1, C9.2, C11.1, C12.1, TP3.1, U1.A5 (VOUT), U1.B5 (VOUT), U1.C5 (VFB), U3.1 (VIN), U4.1 (VIN); also elsewhere on the board
+BATT: C1.1, C2.1, C3.2, C4.2, F1.1, TP2.1, U1.A1 (PVIN), U1.B1 (PVIN), U1.C1 (PVIN), U1.D1 (AVIN), U2.3 (VDD)
/Peripherals/VCC_FLASH: U3.5 (QOD), U3.6 (VOUT); also elsewhere on the board
/Peripherals/VCC_SENSORS: U4.5 (QOD), U4.6 (VOUT); also elsewhere on the board
/Power Supply/LS1_SENSORS_EN: R4.2, U4.3 (ON); also elsewhere on the board
/Power Supply/LS2_FLASH_EN: R3.2, U3.3 (ON); also elsewhere on the board
/STM32 MCU/PA5: C10.1, TP5.1, U1.D5 (BM); also elsewhere on the board
/STM32 MCU/PA8: R2.2, TP4.1, U1.D4 (CE2); also elsewhere on the board
GND: C1.2, C2.2, C3.1, C4.1, C5.1, C7.1, C8.2, C9.1, C10.2, C11.2, C12.2, D1.2 (A2), Q1.1 (G), R2.1, R3.1, R4.1, U1.A3 (PGND), U1.B3 (PGND), U1.C3 (PGND), U1.D3 (AGND), U2.1 (GND), U3.2 (GND), U4.2 (GND); also elsewhere on the board
unnamed: F1.2, Q1.2 (S)
unnamed: L1.1, U1.A4 (BOLX), U1.B4 (BOLX), U1.C4 (BOLX)
unnamed: L1.2, U1.A2 (BULX), U1.B2 (BULX), U1.C2 (BULX)
unnamed: U1.D2 (CE1), U2.2 (~RESET)
Vin: C5.2, D1.1 (A1), Q1.3 (D), TP1.1; also elsewhere on the board

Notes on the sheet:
Load Switch 1 Sensors & Secure Element
Load Switch 2 - Flash
Mounting Holes & Fiducials
Input ESD, Reverse Polarity & Short-Circuit Protection
Buck-Boost Converter
- Vin: 1.8 - 5.5V - Vout: 1.6 - 5.2V - Iout: 300 mA - Iq: 300 nA - Output V: ±1.5% - w/ auto-discharge
- Output: Vin/3 (division ratio) - Supply Current: 100nA - Settling time: ≥ 10ms
~Buck-Boost Specs:
~Battery Monitor (BM):
Enclosure & Logos
Voltage Supervisor Vcut-off = 2.325V

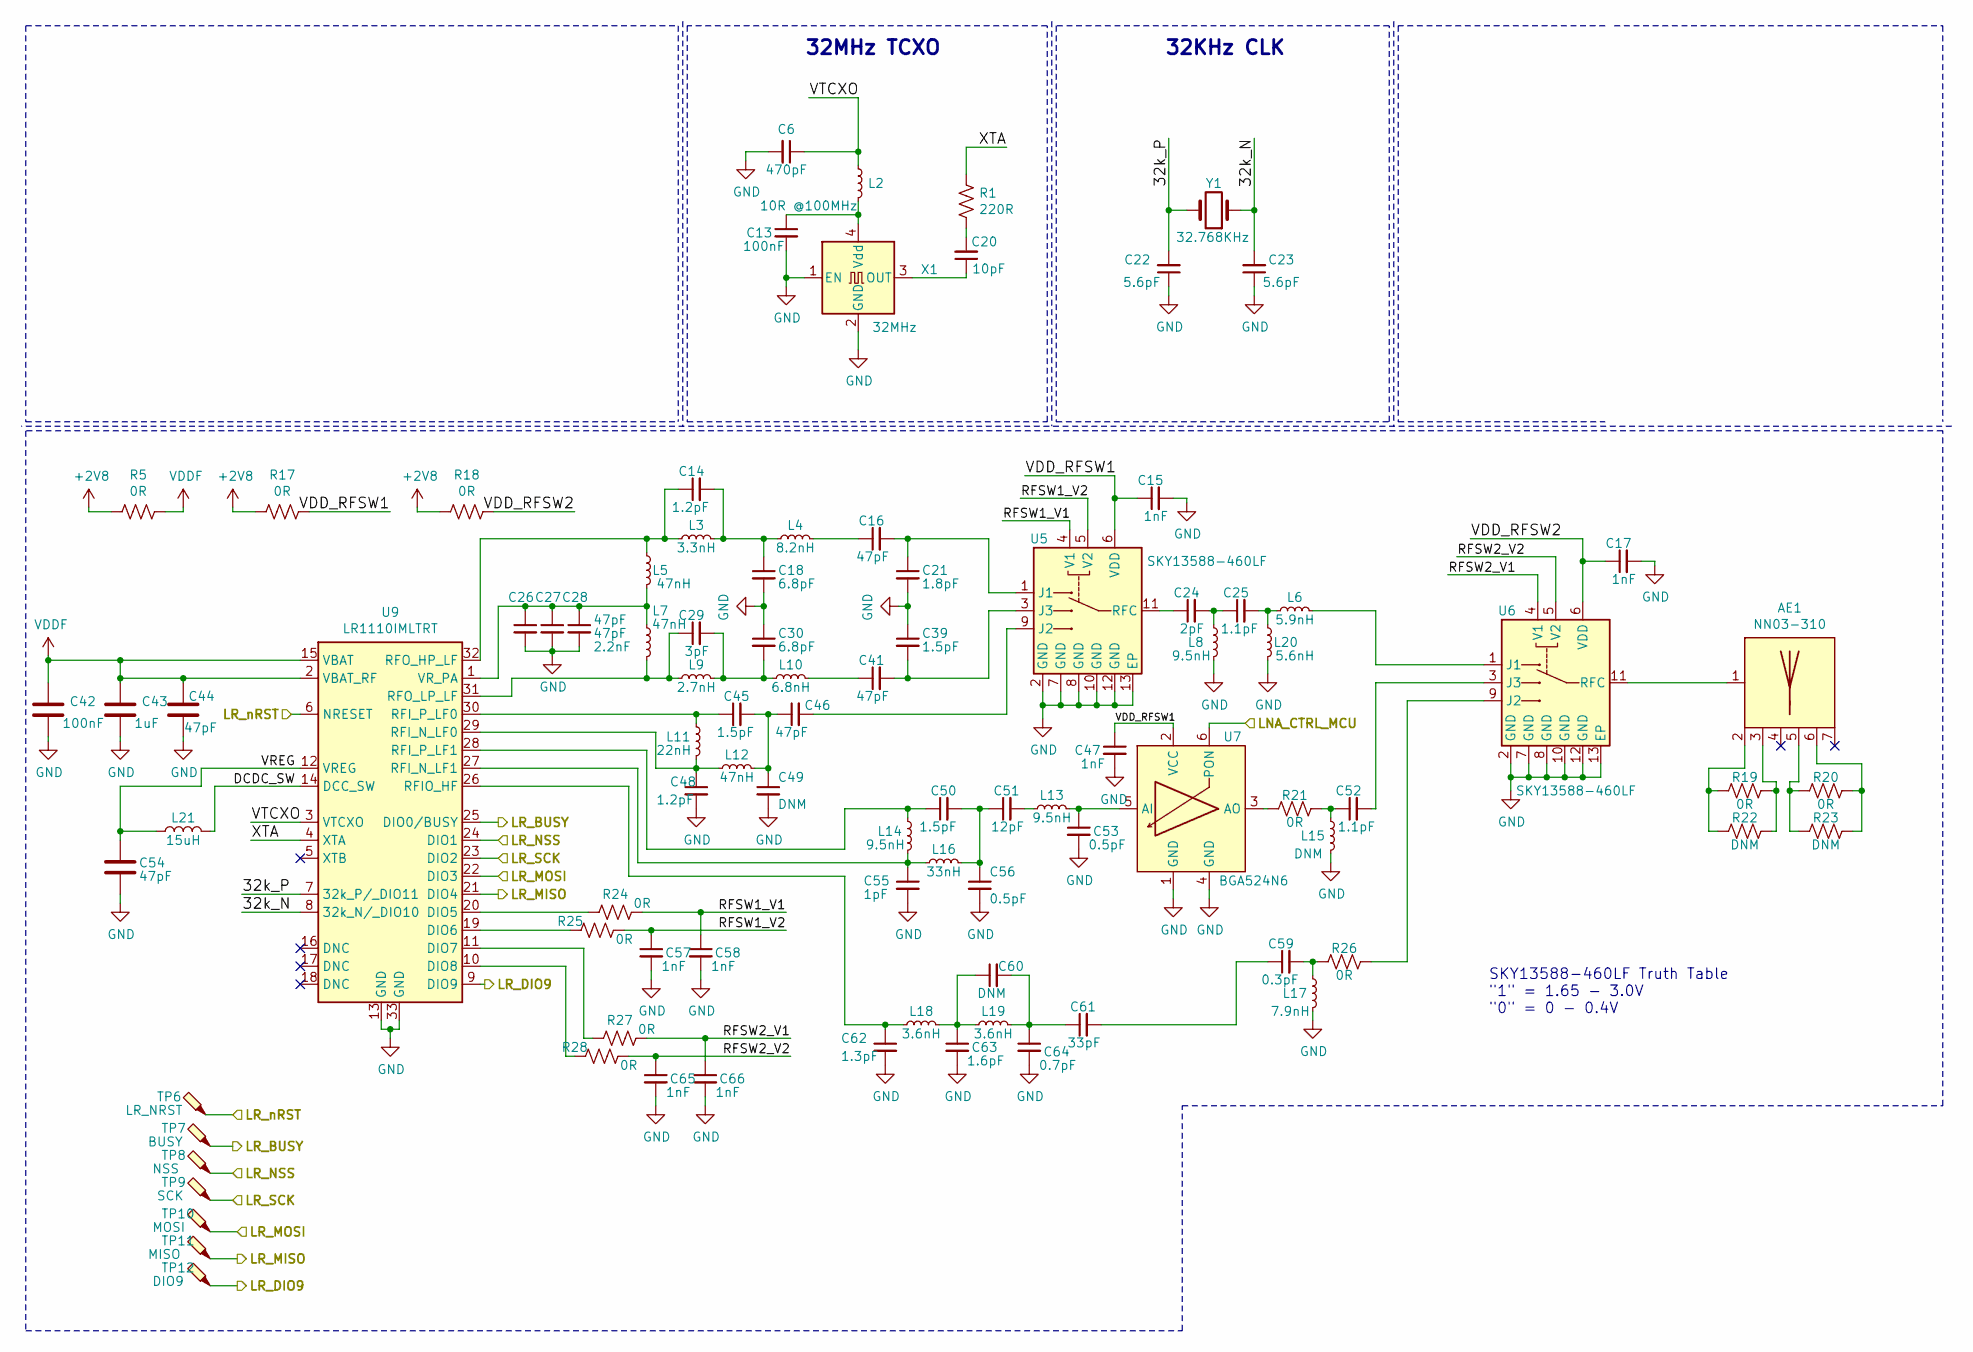
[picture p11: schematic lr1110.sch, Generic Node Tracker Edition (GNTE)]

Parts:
AE1: NN03-310; NN03-310_S; MPN NN03-310
C6: 470pF; C_0402_1005Metric; MPN CL05C471JO5NNNC
C13, C42: 100nF; C_0402_1005Metric; MPN CC0402KRX7R7BB104
C14, C48: 1.2pF; C_0402_1005Metric; MPN GRM1555C1H1R2BA01D
C15, C17, C47, C57, C58, C65, C66: 1nF; C_0402_1005Metric; MPN GRM155R71C102KA01D
C16, C27, C28, C41, C44, C46, C54: 47pF; C_0402_1005Metric; MPN GRM1555C1H470JA01D
C18, C30: 6.8pF; C_0402_1005Metric; MPN GRM1555C1H6R8CA01D
C20: 10pF; C_0402_1005Metric; MPN C0402C100K5RAC7867
C21: 1.8pF; C_0402_1005Metric; MPN GRM1555C1H1R8BA01D
C22, C23: 5.6pF; C_0402_1005Metric; MPN CC0402BRNPO9BN5R6
C24: 2pF; C_0402_1005Metric; MPN GJM1555C1H2R0WB01
C25, C52: 1.1pF; C_0402_1005Metric; MPN GJM1555C1H1R1WB01
C26: 2.2nF; C_0402_1005Metric; MPN GRM155R71H222KA01D
C29: 3pF; C_0402_1005Metric; MPN GRM1555C1H3R0BA01J
C39, C45, C50: 1.5pF; C_0402_1005Metric; MPN GRM1555C1H1R5BA01D
C43: 1uF; C_0402_1005Metric; MPN CL05A105KQ5NNNC
C49, C60: DNM; C_0402_1005Metric
C51: 12pF; C_0402_1005Metric; MPN GRM1555C1H120JA01D
C53, C56: 0.5pF; C_0402_1005Metric; MPN GRM1555C1HR50BA01D
C55: 1pF; C_0402_1005Metric; MPN GRM1555C1H1R0BA01D
C59: 0.3pF; C_0402_1005Metric; MPN GJM1555C1HR30WB01
C61: 33pF; C_0402_1005Metric; MPN GRM1555C1H330JA01D
C62: 1.3pF; C_0402_1005Metric; MPN GRM1555C1H1R3BA01D
C63: 1.6pF; C_0402_1005Metric; MPN GRM1555C1H1R6BA01D
C64: 0.7pF; C_0402_1005Metric; MPN GRM1555C1HR70BA01D
L2: 10R @100MHz; L_0402_1005Metric; MPN BLM15HG102SN1D
L3: 3.3nH; L_0402_1005Metric; MPN LQW15AN3N3C80D
L4: 8.2nH; L_0402_1005Metric; MPN LQW15AN8N2J00D
L5, L7, L12: 47nH; L_0402_1005Metric; MPN LQW15AN47NJ00D
L6: 5.9nH; L_0402_1005Metric; MPN LQW15AN5N9G80
L8, L13, L14: 9.5nH; L_0402_1005Metric; MPN LQW18AN9N5G80
L9: 2.7nH; L_0402_1005Metric; MPN LQW15AN2N7C00D
L10: 6.8nH; L_0402_1005Metric; MPN LQW15AN6N8J00D
L11: 22nH; L_0402_1005Metric; MPN LQW15AN22NH00D
L15: DNM; L_0402_1005Metric; MPN DNM
L16: 33nH; L_0402_1005Metric; MPN LQW15AN33NJ00D
L17: 7.9nH; L_0402_1005Metric; MPN LQW15AN7N9G80
L18, L19: 3.6nH; L_0402_1005Metric; MPN LQW15AN3N6C10D
L20: 5.6nH; L_0402_1005Metric; MPN LQW15AN5N6G80
L21: 15uH; L_0805_2012Metric; MPN MLZ2012M150W
R1: 220R; R_0402_1005Metric; MPN RC0402FR-07220RL
R5, R17, R18, R19, R20, R21, R24, R25, R26, R27, R28: 0R; R_0402_1005Metric
R22, R23: DNM; R_0402_1005Metric
TP6: LR_NRST; TestPoint_Pad_D1.0mm
TP7: BUSY; TestPoint_Pad_D1.0mm
TP8: NSS; TestPoint_Pad_D1.0mm
TP9: SCK; TestPoint_Pad_D1.0mm
TP10: MOSI; TestPoint_Pad_D1.0mm
TP11: MISO; TestPoint_Pad_D1.0mm
TP12: DIO9; TestPoint_Pad_D1.0mm
U5, U6: SKY13588-460LF; sQFN-12-1EP_2x2mm_P0.5mm_EP0.76x0.76mm; MPN SKY13588-460LF
U7: BGA524N6; TSNP-6-2-8; MPN BGA524N6
U9: LR1110IMLTRT; QFN-32-1EP_5x5mm_P0.5mm_EP3.7x3.7mm; MPN LR1110IMLTRT
X1: 32MHz; Crystal_SMD_Abracon_ABM10-4Pin_2.5x2.0mm; MPN TYETBCSANF-32.000000
Y1: 32.768KHz; Crystal_SMD_NX2012SA_32.768KHz; MPN X1A000061002100

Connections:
+2V8: R5.2, R17.2, R18.2; also elsewhere on the board
/LR1110/32k_N: C23.2, U9.8 (32k_N/_DIO10), Y1.1
/LR1110/32k_P: C22.2, U9.7 (32k_P/_DIO11), Y1.2
/LR1110/DCDC_SW: L21.2, U9.14 (DCC_SW)
/LR1110/LNA_CTRL_MCU: U7.6 (PON); also elsewhere on the board
/LR1110/LR_BUSY: TP7.1, U9.25 (DIO0/BUSY); also elsewhere on the board
/LR1110/LR_DIO9: TP12.1, U9.9 (DIO9); also elsewhere on the board
/LR1110/LR_MISO: TP11.1, U9.21 (DIO4); also elsewhere on the board
/LR1110/LR_MOSI: TP10.1, U9.22 (DIO3); also elsewhere on the board
/LR1110/LR_NSS: TP8.1, U9.24 (DIO1); also elsewhere on the board
/LR1110/LR_SCK: TP9.1, U9.23 (DIO2); also elsewhere on the board
/LR1110/LR_nRST: TP6.1, U9.6 (NRESET); also elsewhere on the board
/LR1110/RFSW1_V1: C58.1, R24.1, U5.4 (V1)
/LR1110/RFSW1_V2: C57.1, R25.1, U5.5 (V2)
/LR1110/RFSW2_V1: C66.1, R27.1, U6.4 (V1)
/LR1110/RFSW2_V2: C65.1, R28.1, U6.5 (V2)
/LR1110/VDD_RFSW1: C15.1, C47.1, R17.1, U5.6 (VDD), U7.2 (VCC)
/LR1110/VDD_RFSW2: C17.1, R18.1, U6.6 (VDD)
/LR1110/VREG: C54.1, L21.1, U9.12 (VREG)
/LR1110/VTCXO: C6.1, L2.1, U9.3 (VTCXO)
/LR1110/XTA: R1.1, U9.4 (XTA)
GND: C6.2, C13.2, C15.2, C17.2, C18.2, C21.2, C22.1, C23.1, C26.2, C27.2, C28.2, C30.1, C39.1, C42.2, C43.2, C44.2, C47.2, C48.2, C49.2, C53.2, C54.2, C55.2, C56.2, C57.2, C58.2, C62.2, C63.2, C64.2, C65.2, C66.2, L8.2, L15.2, L17.2, L20.2, U5.2 (GND), U5.7 (GND), U5.8 (GND), U5.10 (GND), U5.12 (GND), U5.13 (EP), U6.2 (GND), U6.7 (GND), U6.8 (GND), U6.10 (GND), U6.12 (GND), U6.13 (EP), U7.1 (GND), U7.4 (GND), U9.13 (GND), U9.33 (GND), X1.1 (EN), X1.2 (GND); also elsewhere on the board
unnamed: AE1.1, U6.11 (RFC)
unnamed: AE1.2, R19.2, R22.2
unnamed: AE1.3, R19.1, R22.1
unnamed: AE1.5, R20.2, R23.2
unnamed: AE1.6, R20.1, R23.1
unnamed: C13.1, L2.2, X1.4 (Vdd)
unnamed: C14.1, L3.1, L5.1, U9.32 (RFO_HP_LF)
unnamed: C14.2, C18.1, L3.2, L4.1
unnamed: C16.1, L4.2
unnamed: C16.2, C21.1, U5.1 (J1)
unnamed: C20.1, X1.3 (OUT)
unnamed: C20.2, R1.2
unnamed: C24.1, U5.11 (RFC)
unnamed: C24.2, C25.1, L8.1
unnamed: C25.2, L6.1, L20.1
unnamed: C26.1, C27.1, C28.1, L5.2, L7.1, U9.1 (VR_PA)
unnamed: C29.1, L7.2, L9.1, U9.31 (RFO_LP_LF)
unnamed: C29.2, C30.2, L9.2, L10.1
unnamed: C39.2, C41.2, U5.3 (J3)
unnamed: C41.1, L10.2
unnamed: C45.1, L11.1, U9.30 (RFI_P_LF0)
unnamed: C45.2, C46.1, C49.1, L12.2
unnamed: C46.2, U5.9 (J2)
unnamed: C48.1, L11.2, L12.1, U9.29 (RFI_N_LF0)
unnamed: C50.1, L14.1, U9.28 (RFI_P_LF1)
unnamed: C50.2, C51.1, C56.1, L16.2
unnamed: C51.2, L13.1
unnamed: C52.1, L15.1, R21.1
unnamed: C52.2, U6.3 (J3)
unnamed: C53.1, L13.2, U7.5 (AI)
unnamed: C55.1, L14.2, L16.1, U9.27 (RFI_N_LF1)
unnamed: C59.1, C61.2
unnamed: C59.2, L17.1, R26.2
unnamed: C60.1, C63.1, L18.2, L19.1
unnamed: C60.2, C61.1, C64.1, L19.2
unnamed: C62.1, L18.1, U9.26 (RFIO_HF)
unnamed: L6.2, U6.1 (J1)
unnamed: R21.2, U7.3 (AO)
unnamed: R24.2, U9.20 (DIO5)
unnamed: R25.2, U9.19 (DIO6)
unnamed: R26.1, U6.9 (J2)
unnamed: R27.2, U9.11 (DIO7)
unnamed: R28.2, U9.10 (DIO8)
VDDF: C42.1, C43.1, C44.1, R5.1, U9.2 (VBAT_RF), U9.15 (VBAT)

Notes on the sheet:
32KHz CLK
32MHz TCXO
SKY13588-460LF Truth Table "1" = 1.65 - 3.0V "0" = 0 - 0.4V

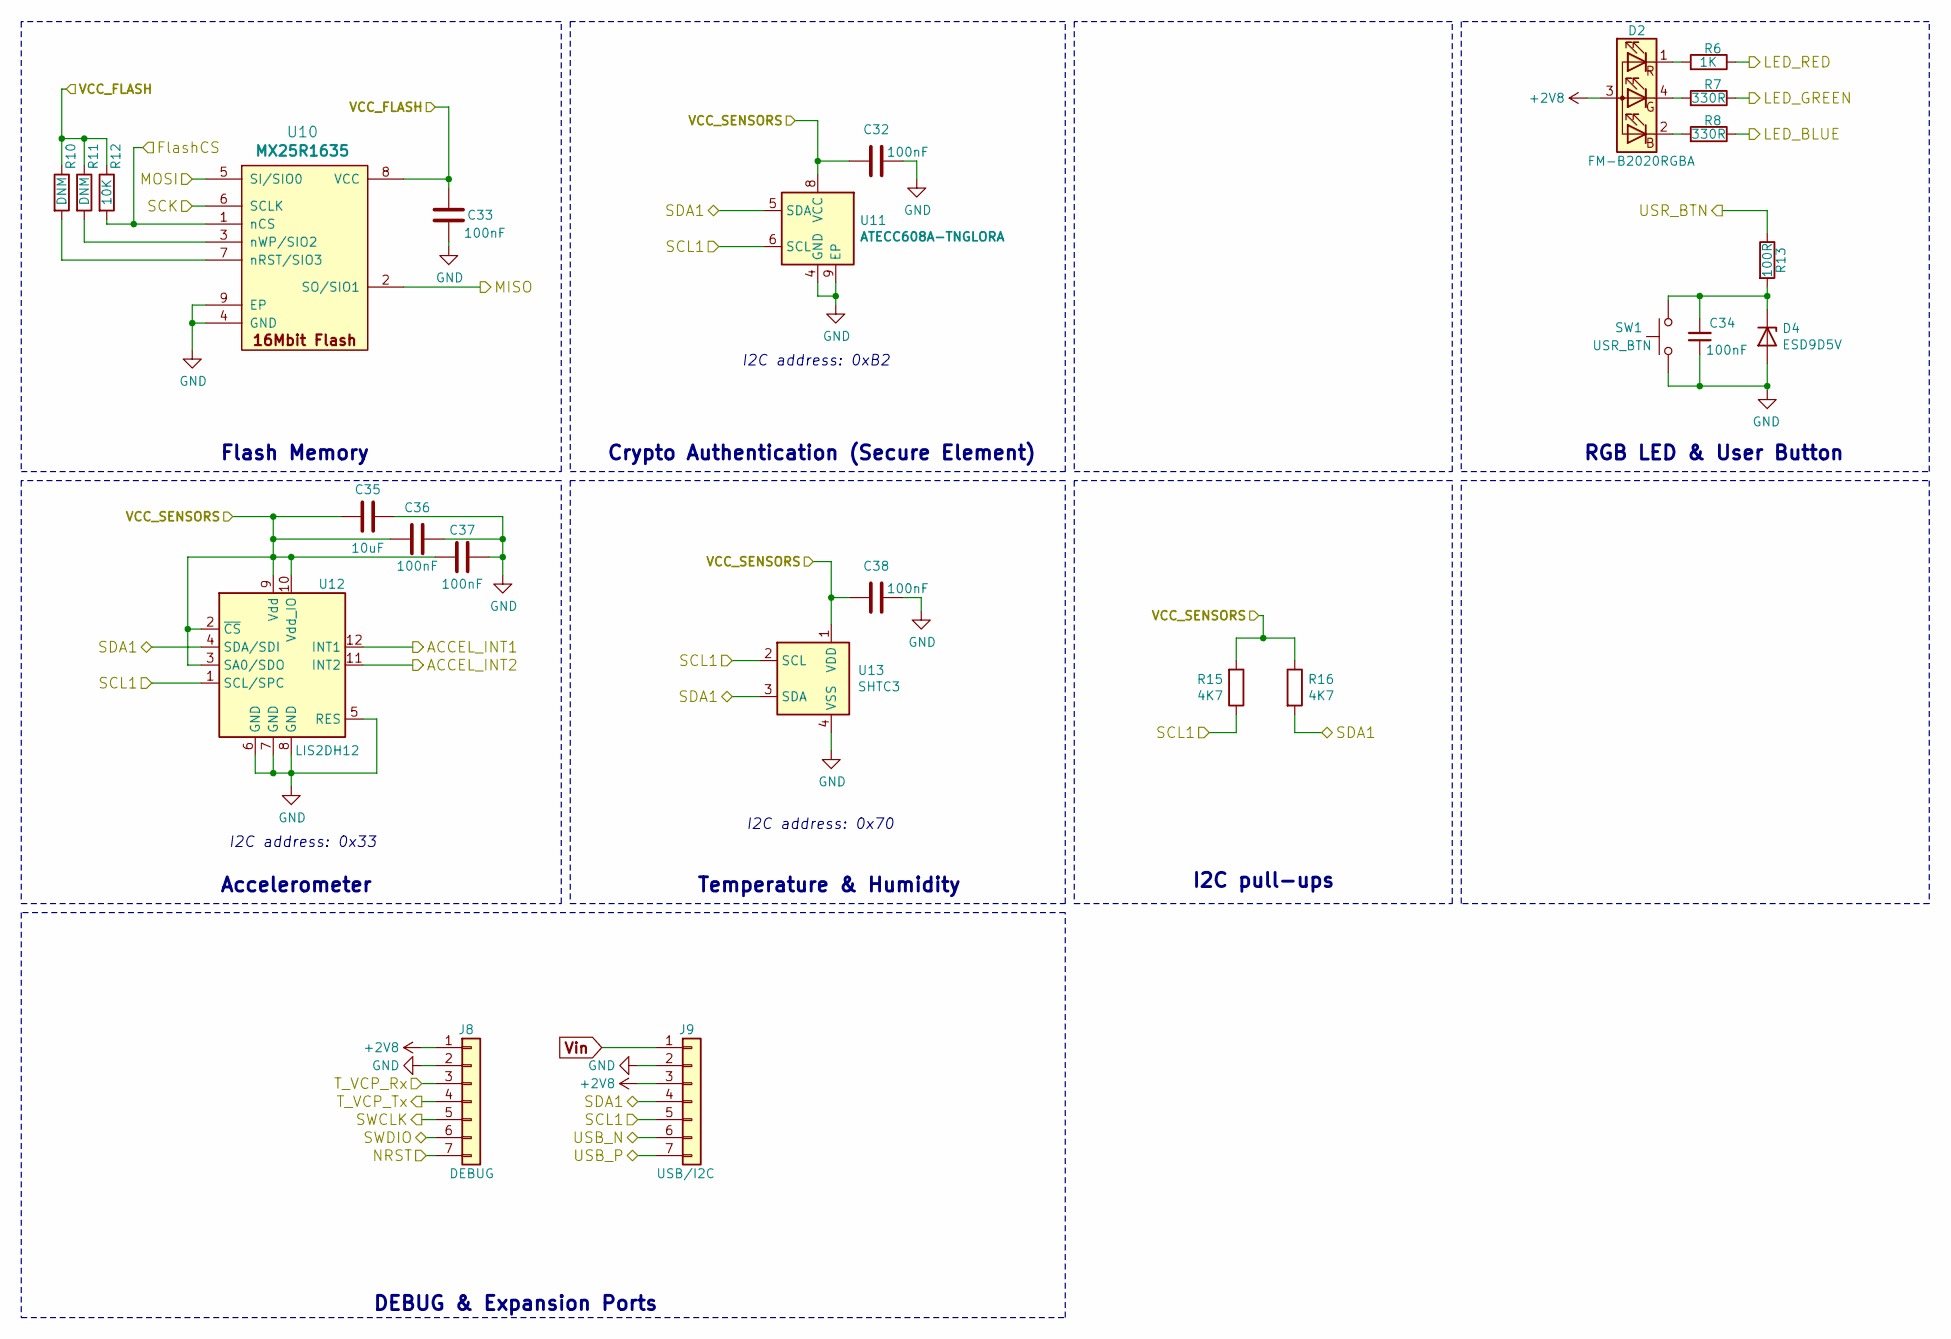
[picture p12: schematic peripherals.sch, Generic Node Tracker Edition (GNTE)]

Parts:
C32, C33, C34, C36, C37, C38: 100nF; C_0402_1005Metric; MPN CC0402KRX7R7BB104
C35: 10uF; C_0402_1005Metric; MPN JMK107ABJ106KA-T
D2: FM-B2020RGBA; LED_Cree-PLCC4_2x2mm_CW; MPN FM-B2020RGBA-HG
D4: ESD9D5V; D_SOD-923; MPN Diode_SMD:D_SOD-923
J8: DEBUG; PinSocket_1x07_P2.54mm_Vertical; MPN DNM
J9: USB/I2C; PinSocket_1x07_P2.54mm_Vertical; MPN DNM
R6: 1K; R_0402_1005Metric; MPN RC0402FR-071KL
R7, R8: 330R; R_0402_1005Metric; MPN AC0402FR-07330RL
R10, R11: DNM; R_0402_1005Metric; MPN DNM
R12: 10K; R_0402_1005Metric; MPN AC0402JR-0710KL
R13: 100R; R_0402_1005Metric; MPN RC0402FR-07100RL
R15, R16: 4K7; R_0402_1005Metric; MPN AC0402FR-074K7L
SW1: USR_BTN; PushButton_UK-B0234-SP25Y; MPN KSC721GLFS
U10: MX25R1635; FLASH_UFDFN-8-MX25R1635F; MPN MX25R1635FZUIL0
U11: ATECC608A-TNGLORA; DFN-8-1EP_3x2mm_P0.5mm_EP1.3x1.5mm; MPN ATECC608A-TNGLORAU-B
U12: LIS2DH12; LGA-12_2x2mm_P0.5mm; MPN LIS2DH12TR
U13: SHTC3; Sensirion_DFN-4-1EP_2x2mm_P1mm_EP0.7x1.6mm; MPN SHTC3

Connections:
+2V8: D2.3 (BK), J8.1, J9.3; also elsewhere on the board
/Peripherals/ACCEL_INT1: U12.12 (INT1); also elsewhere on the board
/Peripherals/ACCEL_INT2: U12.11 (INT2); also elsewhere on the board
/Peripherals/FlashCS: R12.2, U10.1 (nCS); also elsewhere on the board
/Peripherals/LED_BLUE: R8.1; also elsewhere on the board
/Peripherals/LED_GREEN: R7.1; also elsewhere on the board
/Peripherals/LED_RED: R6.1; also elsewhere on the board
/Peripherals/MISO: U10.2 (SO/SIO1); also elsewhere on the board
/Peripherals/MOSI: U10.5 (SI/SIO0); also elsewhere on the board
/Peripherals/NRST: J8.7; also elsewhere on the board
/Peripherals/USB_N: J9.6; also elsewhere on the board
/Peripherals/USB_P: J9.7; also elsewhere on the board
/Peripherals/VCC_FLASH: C33.2, R10.1, R11.1, R12.1, U10.8 (VCC); also elsewhere on the board
/Peripherals/VCC_SENSORS: C32.2, C35.2, C36.2, C37.2, C38.2, R15.2, R16.1, U11.8 (VCC), U12.2 (~CS), U12.3 (SA0/SDO), U12.9 (Vdd), U12.10 (Vdd_IO), U13.1 (VDD); also elsewhere on the board
/STM32 MCU/PA2_USART2_TX: J8.4; also elsewhere on the board
/STM32 MCU/PA3_USART2_RX: J8.3; also elsewhere on the board
/STM32 MCU/PA13_SWDIO: J8.6; also elsewhere on the board
/STM32 MCU/PA14_SWCLK: J8.5; also elsewhere on the board
/STM32 MCU/PB6_I2C1_SCL: J9.5, R15.1, U11.6 (SCL), U12.1 (SCL/SPC), U13.2 (SCL); also elsewhere on the board
/STM32 MCU/PB7_I2C1_SDA: J9.4, R16.2, U11.5 (SDA), U12.4 (SDA/SDI), U13.3 (SDA); also elsewhere on the board
/STM32 MCU/PB13_SPI2_SCK: U10.6 (SCLK); also elsewhere on the board
/STM32 MCU/PC13: R13.1; also elsewhere on the board
GND: C32.1, C33.1, C34.1, C35.1, C36.1, C37.1, C38.1, D4.2 (A), J8.2, J9.2, SW1.2, U10.4 (GND), U10.9 (EP), U11.4 (GND), U11.9 (EP), U12.5 (RES), U12.6 (GND), U12.7 (GND), U12.8 (GND), U13.4 (VSS); also elsewhere on the board
unnamed: C34.2, D4.1 (K), R13.2, SW1.1
unnamed: D2.1 (RK), R6.2
unnamed: D2.2 (GK), R8.2
unnamed: D2.4 (A), R7.2
unnamed: R10.2, U10.7 (nRST/SIO3)
unnamed: R11.2, U10.3 (nWP/SIO2)
Vin: J9.1; also elsewhere on the board

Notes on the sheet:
I2C address: 0x33
Accelerometer
Flash Memory
Crypto Authentication (Secure Element)
RGB LED & User Button
I2C address: 0xB2
Temperature & Humidity
I2C address: 0x70
I2C pull-ups
DEBUG & Expansion Ports

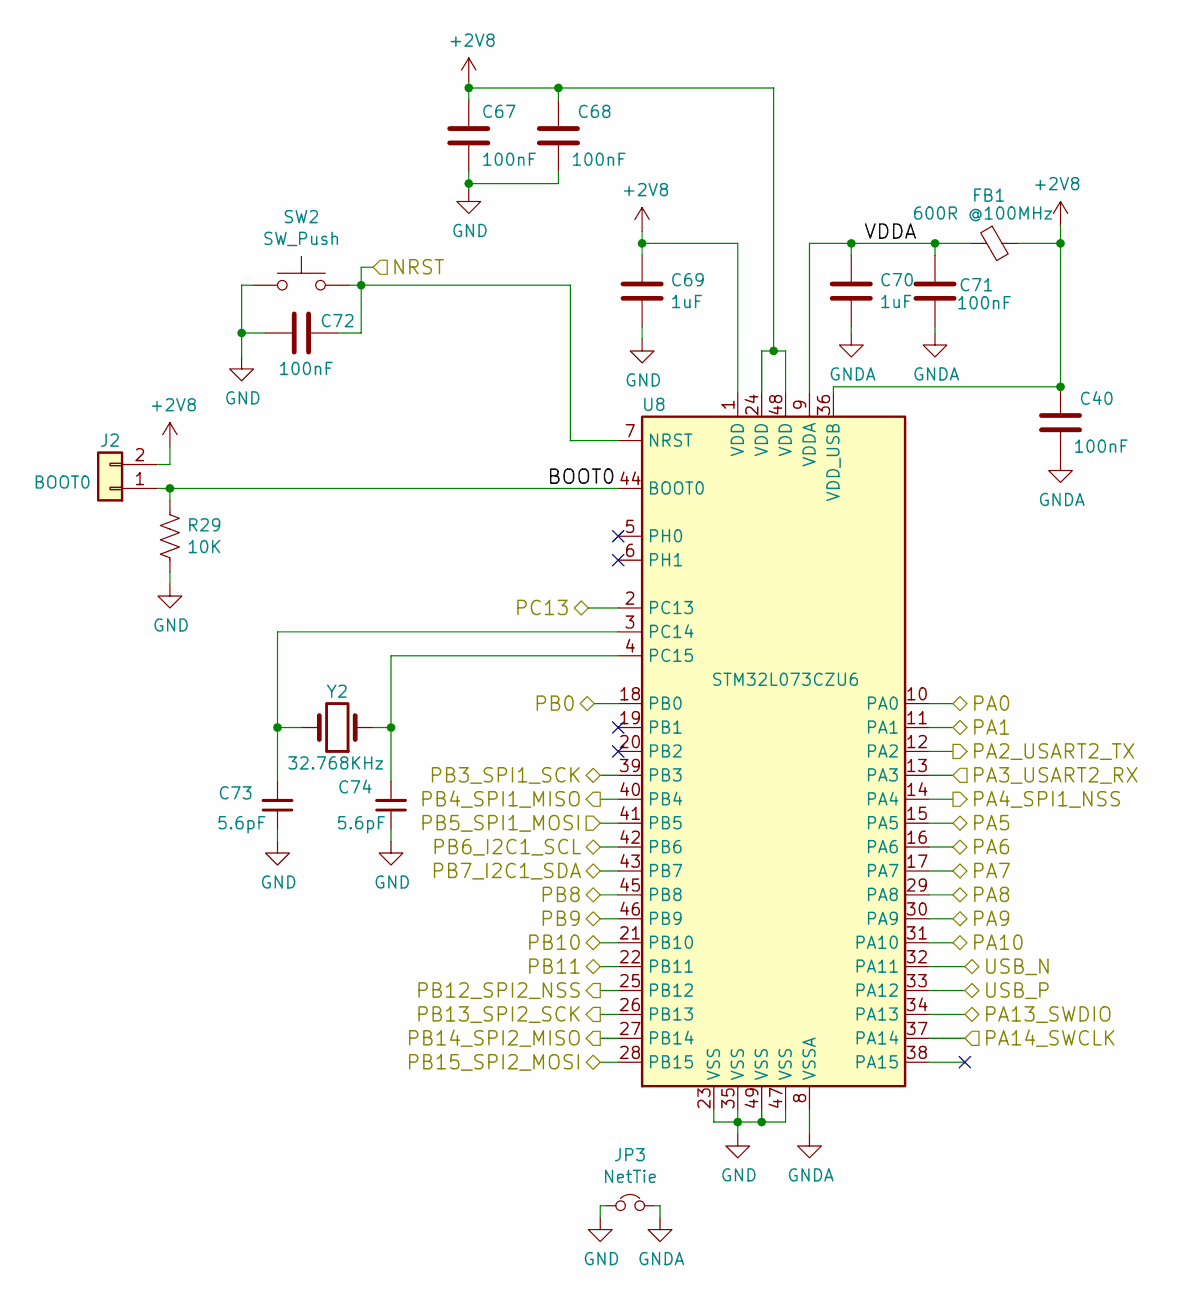
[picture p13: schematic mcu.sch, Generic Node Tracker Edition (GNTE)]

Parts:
C40, C67, C68, C71, C72: 100nF; C_0402_1005Metric; MPN CC0402KRX7R7BB104
C69, C70: 1uF; C_0402_1005Metric; MPN CL05A105KQ5NNNC
C73, C74: 5.6pF; C_0402_1005Metric; MPN CC0402BRNPO9BN5R6
FB1: 600R @100MHz; L_0603_1608Metric; MPN BLM18AG601SN1D
J2: BOOT0; PinHeader_1x02_P1.27mm_Vertical; MPN DNM
JP3: NetTie; SolderJumper-2_P1.3mm_Bridged2Bar_Pad1.0x1.5mm; MPN DNM
R29: 10K; R_0402_1005Metric
SW2: SW_Push; SW_SPST_SKSHABE010
U8: STM32L073CZU6; QFN-48-1EP_7x7mm_P0.5mm_EP5.45x5.45mm; MPN STM32L073CZU6
Y2: 32.768KHz; Crystal_SMD_NX2012SA_32.768KHz; MPN X1A000061002100

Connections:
+2V8: C40.1, C67.1, C68.1, C69.1, FB1.2, J2.2, U8.1 (VDD), U8.24 (VDD), U8.36 (VDD_USB), U8.48 (VDD); also elsewhere on the board
/LR1110/LNA_CTRL_MCU: U8.22 (PB11); also elsewhere on the board
/LR1110/LR_BUSY: U8.21 (PB10); also elsewhere on the board
/LR1110/LR_DIO9: U8.45 (PB8); also elsewhere on the board
/LR1110/LR_MISO: U8.40 (PB4); also elsewhere on the board
/LR1110/LR_MOSI: U8.41 (PB5); also elsewhere on the board
/LR1110/LR_NSS: U8.14 (PA4); also elsewhere on the board
/LR1110/LR_SCK: U8.39 (PB3); also elsewhere on the board
/LR1110/LR_nRST: U8.46 (PB9); also elsewhere on the board
/Peripherals/ACCEL_INT1: U8.10 (PA0); also elsewhere on the board
/Peripherals/ACCEL_INT2: U8.11 (PA1); also elsewhere on the board
/Peripherals/FlashCS: U8.25 (PB12); also elsewhere on the board
/Peripherals/LED_BLUE: U8.18 (PB0); also elsewhere on the board
/Peripherals/LED_GREEN: U8.17 (PA7); also elsewhere on the board
/Peripherals/LED_RED: U8.16 (PA6); also elsewhere on the board
/Peripherals/MISO: U8.27 (PB14); also elsewhere on the board
/Peripherals/MOSI: U8.28 (PB15); also elsewhere on the board
/Peripherals/NRST: C72.1, SW2.2, U8.7 (NRST); also elsewhere on the board
/Peripherals/USB_N: U8.32 (PA11); also elsewhere on the board
/Peripherals/USB_P: U8.33 (PA12); also elsewhere on the board
/Power Supply/LS1_SENSORS_EN: U8.31 (PA10); also elsewhere on the board
/Power Supply/LS2_FLASH_EN: U8.30 (PA9); also elsewhere on the board
/STM32 MCU/BOOT0: J2.1, R29.1, U8.44 (BOOT0)
/STM32 MCU/PA2_USART2_TX: U8.12 (PA2); also elsewhere on the board
/STM32 MCU/PA3_USART2_RX: U8.13 (PA3); also elsewhere on the board
/STM32 MCU/PA5: U8.15 (PA5); also elsewhere on the board
/STM32 MCU/PA8: U8.29 (PA8); also elsewhere on the board
/STM32 MCU/PA13_SWDIO: U8.34 (PA13); also elsewhere on the board
/STM32 MCU/PA14_SWCLK: U8.37 (PA14); also elsewhere on the board
/STM32 MCU/PB6_I2C1_SCL: U8.42 (PB6); also elsewhere on the board
/STM32 MCU/PB7_I2C1_SDA: U8.43 (PB7); also elsewhere on the board
/STM32 MCU/PB13_SPI2_SCK: U8.26 (PB13); also elsewhere on the board
/STM32 MCU/PC13: U8.2 (PC13); also elsewhere on the board
/STM32 MCU/VDDA: C70.1, C71.1, FB1.1, U8.9 (VDDA)
GND: C67.2, C68.2, C69.2, C72.2, C73.1, C74.1, JP3.1, R29.2, SW2.1, U8.23 (VSS), U8.35 (VSS), U8.47 (VSS), U8.49 (VSS); also elsewhere on the board
GNDA: C40.2, C70.2, C71.2, JP3.2, U8.8 (VSSA)
unnamed: C73.2, U8.3 (PC14), Y2.2
unnamed: C74.2, U8.4 (PC15), Y2.1

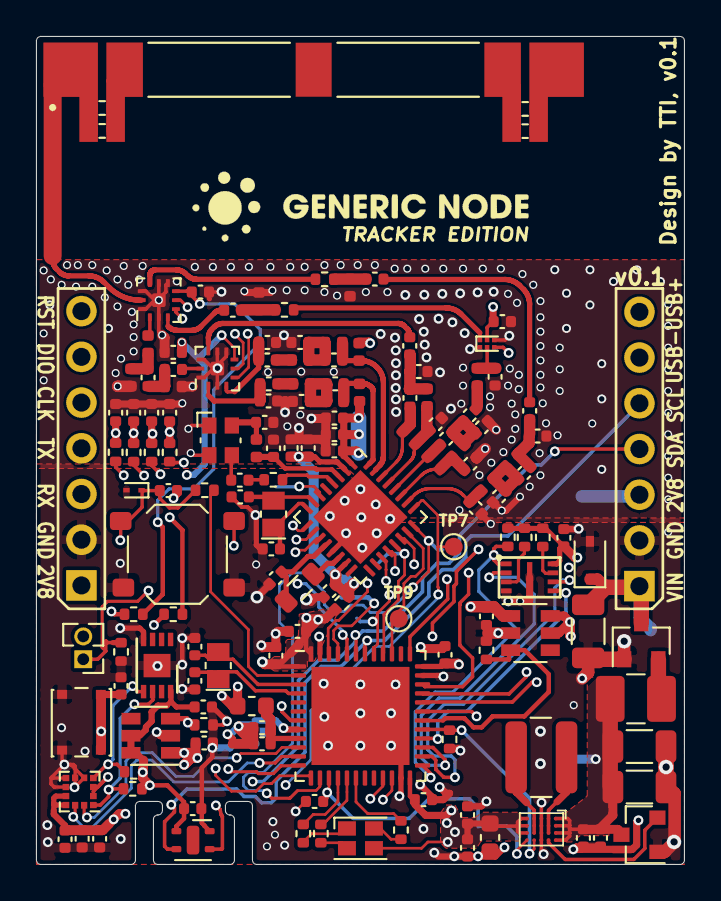
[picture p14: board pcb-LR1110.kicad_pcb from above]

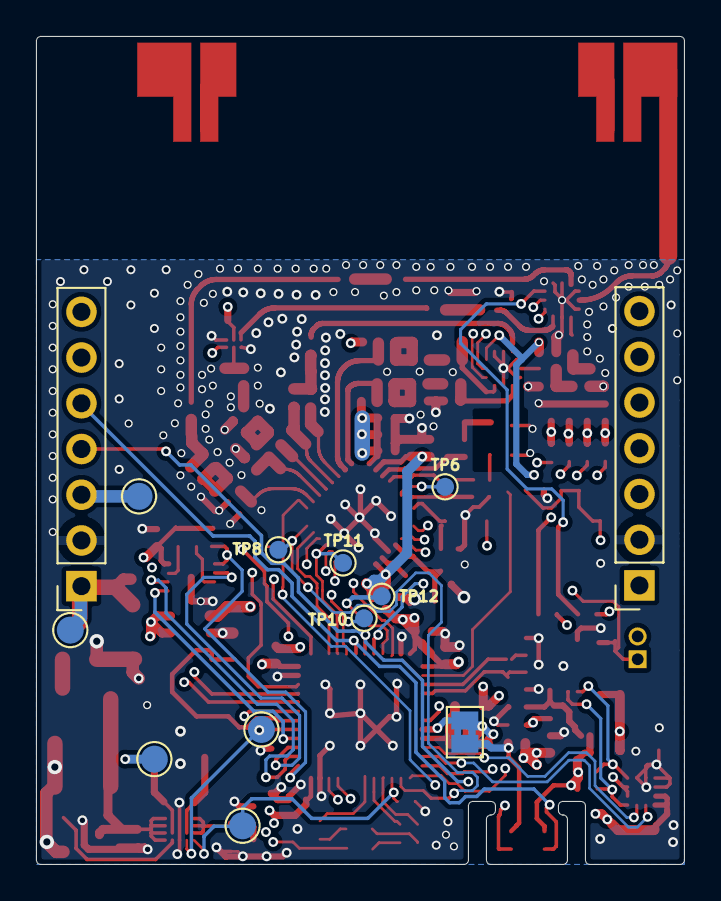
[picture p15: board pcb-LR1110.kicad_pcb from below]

Board: 4 copper layers, 36.0 x 46.0 mm, 161 parts (13 on the bottom side), 108 nets.

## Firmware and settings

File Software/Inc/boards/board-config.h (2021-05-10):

/*!
 * \file      board-config.h
 *
 * \brief     board specific pinout
 *
 * Revised BSD License
 * Copyright Semtech Corporation 2020. All rights reserved.
 *
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
 * THIS SOFTWARE IS PROVIDED BY THE COPYRIGHT HOLDERS AND CONTRIBUTORS "AS IS"
 * AND ANY EXPRESS OR IMPLIED WARRANTIES, INCLUDING, BUT NOT LIMITED TO, THE
 * IMPLIED WARRANTIES OF MERCHANTABILITY AND FITNESS FOR A PARTICULAR PURPOSE
 * ARE DISCLAIMED. IN NO EVENT SHALL SEMTECH CORPORATION BE LIABLE FOR ANY
 * DIRECT, INDIRECT, INCIDENTAL, SPECIAL, EXEMPLARY, OR CONSEQUENTIAL DAMAGES
 * (INCLUDING, BUT NOT LIMITED TO, PROCUREMENT OF SUBSTITUTE GOODS OR SERVICES;
 * LOSS OF USE, DATA, OR PROFITS; OR BUSINESS INTERRUPTION) HOWEVER CAUSED AND
 * ON ANY THEORY OF LIABILITY, WHETHER IN CONTRACT, STRICT LIABILITY, OR TORT
 * (INCLUDING NEGLIGENCE OR OTHERWISE) ARISING IN ANY WAY OUT OF THE USE OF THIS
 * SOFTWARE, EVEN IF ADVISED OF THE POSSIBILITY OF SUCH DAMAGE.
 */

#ifndef __BOARD_CONFIG_H__
#define __BOARD_CONFIG_H__

#ifdef __cplusplus
extern "C" {
#endif

/*
 * -----------------------------------------------------------------------------
 * --- DEPENDENCIES ------------------------------------------------------------
 */

/*
 * -----------------------------------------------------------------------------
 * --- PUBLIC MACROS -----------------------------------------------------------
 */

/*
 * -----------------------------------------------------------------------------
 * --- PUBLIC CONSTANTS --------------------------------------------------------
 */

/*!
 * \brief Defines the time required for the TCXO to wakeup [ms].
 */
#if defined( LR1110EVK )
#define BOARD_TCXO_WAKEUP_TIME                      5
#else
#define BOARD_TCXO_WAKEUP_TIME                      0
#endif

/*!
 * Board MCU pins definitions
 */

//Radio specific pinout and peripherals
#define RADIO_SPI_MOSI          PB_5
#define RADIO_SPI_MISO          PB_4
#define RADIO_SPI_SCLK          PB_3
#define RADIO_NSS               PA_4
#define RADIO_NRST              PB_9
#define RADIO_EVENT             PB_8
#define RADIO_BUSY_PIN          PB_10
#define RADIO_RESET             PB_9


#define LNA_PON                 PB_11
#define RADIO_FREQ_SEL          PB_2
#define RADIO_DEVICE_SEL        PA_15

#define LED_TX                  PA_6
#define LED_RX                  PB_0

#define ACC_INT1                PA_0

#define OSC_LSE_IN_PIN          PC_14
#define OSC_LSE_OUT_PIN         PC_15

#define OSC_HSE_IN_PIN          PH_0
#define OSC_HSE_OUT             PH_1

#define SWCLK_PIN               PA_14
#define SWDAT_PIN               PA_13

#define I2C_SCL                 PB_6
#define I2C_SDA                 PB_7

#define UART_TX                 PA_2
#define UART_RX                 PA_3

/*
 * -----------------------------------------------------------------------------
 * --- PUBLIC TYPES ------------------------------------------------------------
 */

/*
 * -----------------------------------------------------------------------------
 * --- PUBLIC FUNCTIONS PROTOTYPES ---------------------------------------------
 */

#ifdef __cplusplus
}
#endif

#endif  // __BOARD_CONFIG_H__

/* --- EOF ------------------------------------------------------------------ */

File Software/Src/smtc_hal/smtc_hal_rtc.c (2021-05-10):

/*!
 * \file      smtc_hal_rtc.c
 *
 * \brief     Board specific package RTC API implementation
 *
 * Revised BSD License
 * Copyright Semtech Corporation 2020. All rights reserved.
 *
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
 * THIS SOFTWARE IS PROVIDED BY THE COPYRIGHT HOLDERS AND CONTRIBUTORS "AS IS"
 * AND ANY EXPRESS OR IMPLIED WARRANTIES, INCLUDING, BUT NOT LIMITED TO, THE
 * IMPLIED WARRANTIES OF MERCHANTABILITY AND FITNESS FOR A PARTICULAR PURPOSE
 * ARE DISCLAIMED. IN NO EVENT SHALL SEMTECH CORPORATION BE LIABLE FOR ANY
 * DIRECT, INDIRECT, INCIDENTAL, SPECIAL, EXEMPLARY, OR CONSEQUENTIAL DAMAGES
 * (INCLUDING, BUT NOT LIMITED TO, PROCUREMENT OF SUBSTITUTE GOODS OR SERVICES;
 * LOSS OF USE, DATA, OR PROFITS; OR BUSINESS INTERRUPTION) HOWEVER CAUSED AND
 * ON ANY THEORY OF LIABILITY, WHETHER IN CONTRACT, STRICT LIABILITY, OR TORT
 * (INCLUDING NEGLIGENCE OR OTHERWISE) ARISING IN ANY WAY OUT OF THE USE OF THIS
 * SOFTWARE, EVEN IF ADVISED OF THE POSSIBILITY OF SUCH DAMAGE.
 */

 /*
 * -----------------------------------------------------------------------------
 * --- DEPENDENCIES ------------------------------------------------------------
 */

#include <time.h>
#include <math.h>
#include "stm32l0xx_hal.h"
#include "stm32l0xx_ll_rtc.h"
#include "smtc_hal_mcu.h"
#include "smtc_hal_rtc.h"
#include "smtc_hal_tmr_list.h"

/*
 * -----------------------------------------------------------------------------
 * --- PRIVATE MACROS-----------------------------------------------------------
 */

/*
 * -----------------------------------------------------------------------------
 * --- PRIVATE CONSTANTS -------------------------------------------------------
 */

// MCU Wake Up Time
#define MIN_ALARM_DELAY_IN_TICKS       3U              // in ticks

// sub-second number of bits
#define N_PREDIV_S                     10U

// Synchronous prediv
#define PREDIV_S                       ( ( 1U << N_PREDIV_S ) - 1U )

// Asynchronous prediv
#define PREDIV_A                       ( ( 1U << ( 15U - N_PREDIV_S ) ) - 1U )

// Sub-second mask definition
#define ALARM_SUBSECOND_MASK           ( N_PREDIV_S << RTC_ALRMASSR_MASKSS_Pos )

// RTC Time base in us
#define USEC_NUMBER                    1000000U
#define MSEC_NUMBER                    ( USEC_NUMBER / 1000 )

#define COMMON_FACTOR                  3U
#define CONV_NUMER                     ( MSEC_NUMBER >> COMMON_FACTOR )
#define CONV_DENOM                     ( 1U << ( N_PREDIV_S - COMMON_FACTOR ) )

/*!
 * Days, Hours, Minutes and seconds
 */
#define DAYS_IN_LEAP_YEAR              ( ( uint32_t ) 366U )
#define DAYS_IN_YEAR                   ( ( uint32_t ) 365U )
#define SECONDS_IN_1DAY                ( ( uint32_t ) 86400U )
#define SECONDS_IN_1HOUR               ( ( uint32_t ) 3600U )
#define SECONDS_IN_1MINUTE             ( ( uint32_t ) 60U )
#define MINUTES_IN_1HOUR               ( ( uint32_t ) 60U )
#define HOURS_IN_1DAY                  ( ( uint32_t ) 24U )

/*!
 * Correction factors
 */
#define DAYS_IN_MONTH_CORRECTION_NORM  ( ( uint32_t ) 0x99AAA0 )
#define DAYS_IN_MONTH_CORRECTION_LEAP  ( ( uint32_t ) 0x445550 )

/*!
 * Calculates ceiling( X / N )
 */
#define DIVC( X, N )                   ( ( ( X ) + ( N ) -1 ) / ( N ) )

/*
 * -----------------------------------------------------------------------------
 * --- PRIVATE TYPES -----------------------------------------------------------
 */

/*
 * -----------------------------------------------------------------------------
 * --- PRIVATE VARIABLES -------------------------------------------------------
 */

hal_rtc_t hal_rtc;

/*!
 * \brief RTC Alarm
 */
static RTC_AlarmTypeDef rtc_alarm;

/*!
 * \brief Number of days in each month on a normal year
 */
static const uint8_t days_in_month[] = { 31, 28, 31, 30, 31, 30, 31, 31, 30, 31, 30, 31 };

/*!
 * \brief Number of days in each month on a leap year
 */
static const uint8_t days_in_month_leap_year[] = { 31, 29, 31, 30, 31, 30, 31, 31, 30, 31, 30, 31 };

/*
 * -----------------------------------------------------------------------------
 * --- PRIVATE FUNCTIONS DECLARATION -------------------------------------------
 */

/*!
 * \brief Converts time in ms to time in wake up timer ticks
 * Assuming WUCKSEL[2:0] = 000: RTCCLK/16 clock is selected
 *
 * \param [in] milliseconds Time in milliseconds
 * \retval ticks Time in wake up timer ticks
 */
static uint32_t hal_rtc_ms_2_wakeup_timer_tick( const uint32_t milliseconds );

/*!
 * \brief Converts time in s to time in wake up timer ticks
 * When RTCCLK = 32768 Hz and ck_spre (Synchronous prescaler output clock) is
 * adjusted to 1 Hz
 *
 * \param [in] seconds Time in seconds
 * \retval ticks Time in wake up timer ticks
 */
static uint32_t hal_rtc_s_2_wakeup_timer_tick( const uint32_t seconds );

/*!
 * \brief Get the elapsed time in seconds and milliseconds since RTC initialization
 *
 * \param [out] milliseconds Number of milliseconds elapsed since RTC
 *                           initialization
 * \retval seconds           Number of seconds elapsed since RTC initialization
 */
static uint32_t hal_rtc_get_calendar_time( uint16_t* milliseconds );

/*!
 * \brief Get current full resolution RTC timestamp in ticks
 *
 * \retval timestamp_in_ticks Current timestamp in ticks
 */
static uint64_t rtc_get_timestamp_in_ticks( RTC_DateTypeDef* date, RTC_TimeTypeDef* time );

void hal_rtc_init( void )
{
    RTC_TimeTypeDef time;
    RTC_DateTypeDef date;

    hal_rtc.handle.Instance            = RTC;
    hal_rtc.handle.Init.HourFormat     = RTC_HOURFORMAT_24;
    hal_rtc.handle.Init.AsynchPrediv   = PREDIV_A;
    hal_rtc.handle.Init.SynchPrediv    = PREDIV_S;
    hal_rtc.handle.Init.OutPut         = RTC_OUTPUT_DISABLE;
    hal_rtc.handle.Init.OutPutRemap    = RTC_OUTPUT_REMAP_NONE;
    hal_rtc.handle.Init.OutPutPolarity = RTC_OUTPUT_POLARITY_HIGH;
    hal_rtc.handle.Init.OutPutType     = RTC_OUTPUT_TYPE_OPENDRAIN;

    if( HAL_RTC_Init( &hal_rtc.handle ) != HAL_OK )
    {
        hal_mcu_panic( );
    }

    // Initialize RTC counter to 0
    date.Year    = 0;
    date.Month   = RTC_MONTH_JANUARY;
    date.Date    = 1;
    date.WeekDay = RTC_WEEKDAY_MONDAY;
    HAL_RTC_SetDate( &hal_rtc.handle, &date, RTC_FORMAT_BIN );

    /*at 0:0:0*/
    time.Hours          = 0;
    time.Minutes        = 0;
    time.Seconds        = 0;
    time.SubSeconds     = 0;
    time.TimeFormat     = 0;
    time.StoreOperation = RTC_DAYLIGHTSAVING_NONE;
    time.DayLightSaving = RTC_STOREOPERATION_RESET;
    HAL_RTC_SetTime( &hal_rtc.handle, &time, RTC_FORMAT_BIN );

    // Enable Direct Read of the calendar registers (not through Shadow
    // registers)
    HAL_RTCEx_EnableBypassShadow( &hal_rtc.handle );

    // Init alarm.
    HAL_RTC_DeactivateAlarm( &hal_rtc.handle, RTC_ALARM_A );

    hal_rtc_set_time_ref_in_ticks( );
}

uint32_t hal_rtc_get_time_s( void )
{
    uint16_t milliseconds = 0;
    return hal_rtc_get_calendar_time( &milliseconds );
}
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

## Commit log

2021-05-04 sch: Add schematics pdf file of STM32L0 and LR1110
2021-05-07 hw: Add KiCAD project files and production assets
    [lr1110.sch, mcu.sch, pcb-LR1110-BOM.xlsx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]
2021-05-09 doc: Add device renders and update readme on applications and SW setup
